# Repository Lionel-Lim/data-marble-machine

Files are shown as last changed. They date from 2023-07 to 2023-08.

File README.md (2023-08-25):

# **Data Marble Machine: A Visual and Interactive Approach to Energy Awareness**

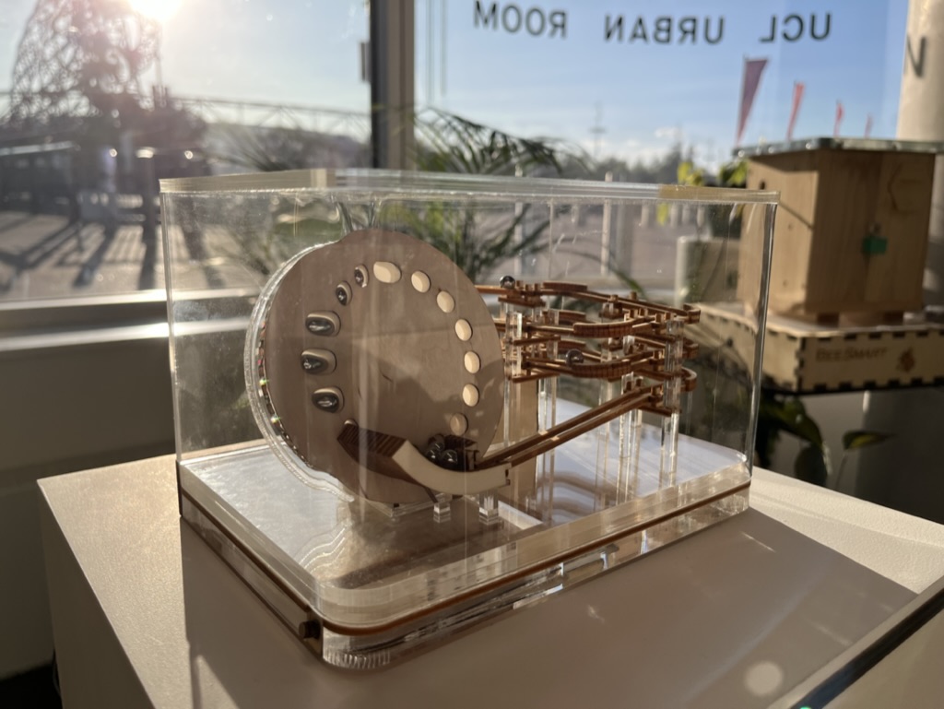
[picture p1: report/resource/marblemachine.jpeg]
Marble Machine on a plinth
<p align="center"> 

## **Project Overview**

This project showcases the innovative "Marble Machine," a device bridging the gap between art and technology. By converting real-time energy consumption data into tangible movement of marbles, this device provides a captivating visual and auditory experience. Accompanied by a user-friendly web application, this project seeks to revolutionise the way users interact with their energy consumption data.

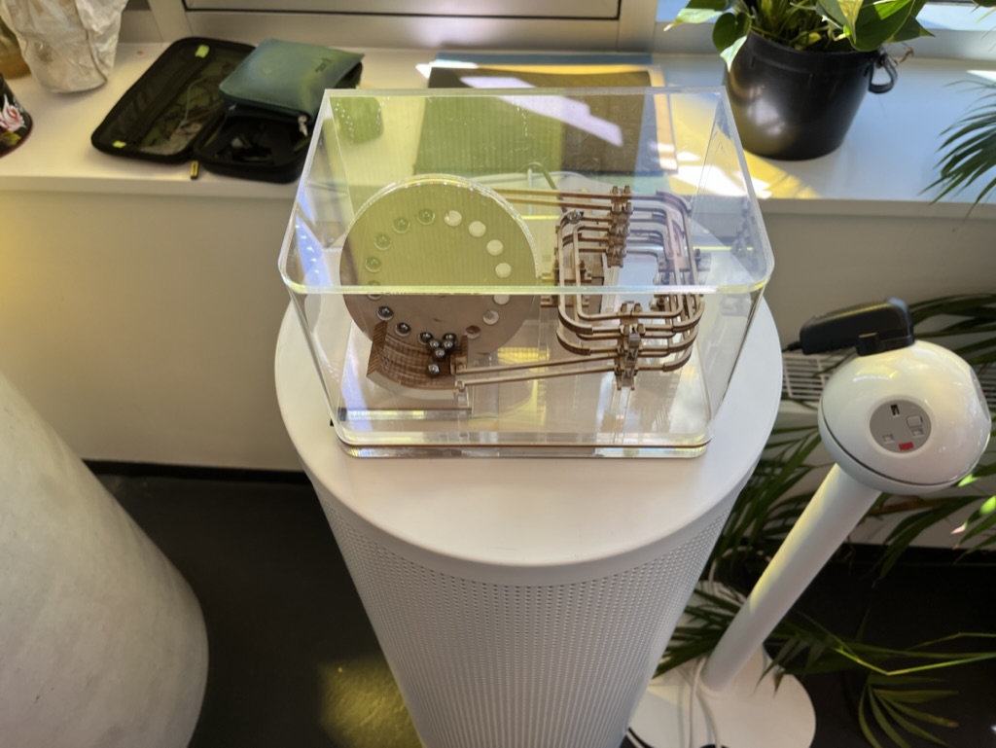
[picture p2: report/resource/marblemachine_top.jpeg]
Marble machine on a pillar
<p align="center"> 

### **Key Features**

- Transforms real-time energy consumption into marble movement.
- Provides both visual and auditory feedback.
- Created using modern techniques like laser cutting and 3D printing.
- Accompanying web application for detailed energy data insights.

## **Getting Started**

### **Prerequisites**

- Ensure you have [Flutter](https://flutter.dev/docs/get-started/install) installed for web application setup.
- Necessary hardware components for the Marble Machine.
- Basic understanding of IoT device operation.

### **Application Installation**

1. **Clone the Repository**

```
git clone https://github.com/Lionel-Lim/data-marble-machine
```

1. Navigate to the cloned directory.
2. Follow the instructions in the 'How to Make' section - Web Application Setup.

## **How to Make**

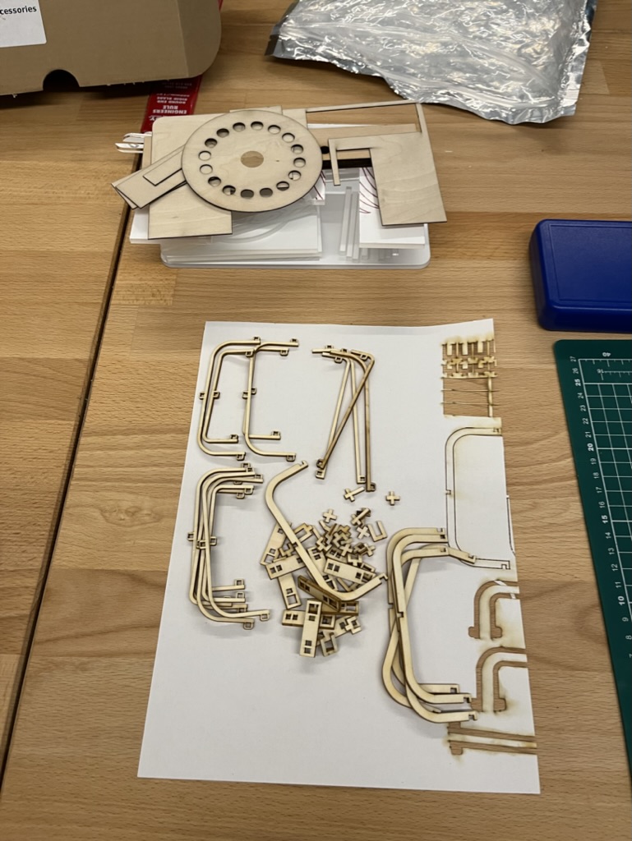
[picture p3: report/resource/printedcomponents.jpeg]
Printed materials
<p align="center"> 

1. **Required Components, Materials and Machines**
- **Components**
    - [Adafruit ESP32 Feather V2 - 8MB Flash + 2 MB PSRAM - STEMMA QT](https://www.adafruit.com/product/5400 "https://www.adafruit.com/product/5400")
    - [Ultra Skinny NeoPixel 1515 LED Strip 4mm wide (0.5 meter long - 75 LEDs)](https://thepihut.com/products/ultra-skinny-neopixel-1515-led-strip-4mm-wide "https://thepihut.com/products/ultra-skinny-neopixel-1515-led-strip-4mm-wide")
    - [DC Motor + Stepper FeatherWing Add-on For All Feather Boards](https://www.adafruit.com/product/2927 "https://www.adafruit.com/product/2927")
    - [Micro Mini N20 DC Motor with gear box](https://www.amazon.co.uk/HALJIA-300RPM-Reducing-Reduction-Terminals/dp/B07YB76TGS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 "https://www.amazon.co.uk/HALJIA-300RPM-Reducing-Reduction-Terminals/dp/B07YB76TGS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")
    - [Female DC Power adapter - 2.1mm jack to screw terminal block](https://thepihut.com/products/female-dc-power-adapter-2-1mm-jack-to-screw-terminal-block "https://thepihut.com/products/female-dc-power-adapter-2-1mm-jack-to-screw-terminal-block")
    - Wires
    - Ball bearing (6mm x 16mm x 6mm)
    - Wooden Dowel Pins (6mm x 30mm)
- **Materials**
    - 1.8, 5, 10mm Transparent Acrylic Sheet
    - 1, 2.5, 5mm Wood Sheet
- **Machines**
    - Trotec Speedy 400 or equivalent
    - Prusa i3 MK3S or equivalent

3. **Hardware Setup**
- Navigate to `models/final`
- Cut required components as per the name of the files.
- Assemble the primary structure using the laser-cut pieces.
- Integrate the sensors and ensure they are correctly calibrated.
- Connect the device to a power source.
2. **Web Application Setup**
- **Start from beginning**
    - Navigate to the `code/app/elow` directory.
    - Install necessary dependencies using `flutter pub get`.
    - Run the application using `flutter run`. (Tested in Edge, Android and iOS)
- or use pre-built files
    - Navigate to `firebase/public` 
    - Upload all files to hosting platform

## Circuit Diagram
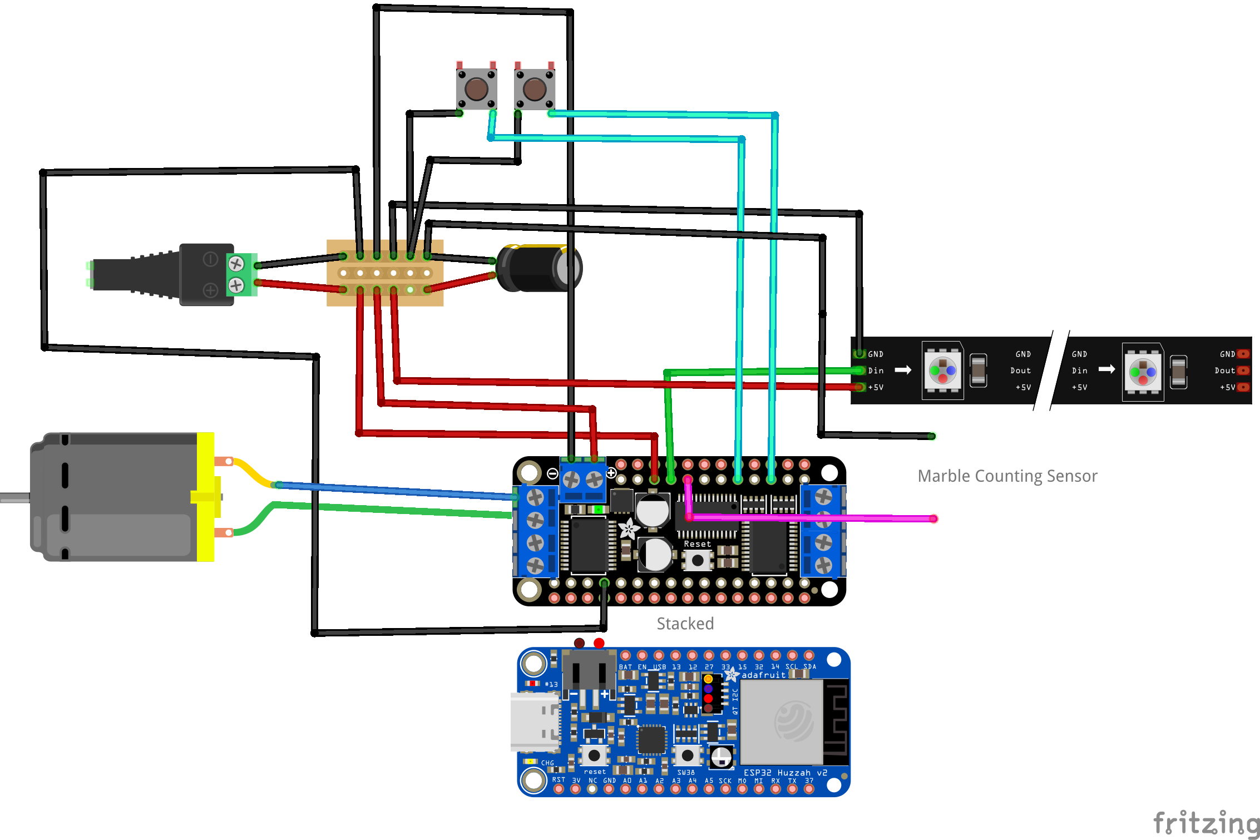
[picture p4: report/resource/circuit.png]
Circuit Diagram
<p align="center"> 

## Exhibition
The project is currently on public display at UCL East Urban Room.

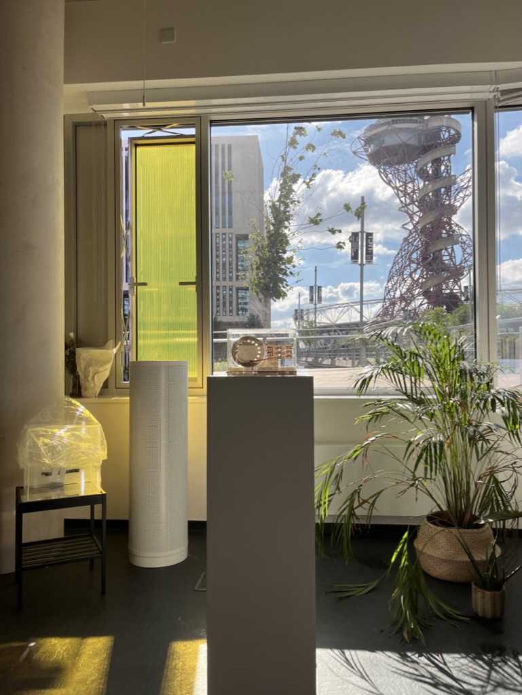
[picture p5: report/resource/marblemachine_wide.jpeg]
Exhibited Project
<p align="center"> 

##

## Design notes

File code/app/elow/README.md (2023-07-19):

# elow

A new Flutter project.

## Getting Started

This project is a starting point for a Flutter application.

A few resources to get you started if this is your first Flutter project:

- [Lab: Write your first Flutter app](https://docs.flutter.dev/get-started/codelab)
- [Cookbook: Useful Flutter samples](https://docs.flutter.dev/cookbook)

For help getting started with Flutter development, view the
[online documentation](https://docs.flutter.dev/), which offers tutorials,
samples, guidance on mobile development, and a full API reference.

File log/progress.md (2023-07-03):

# Making progress
## 24 June 2023
1. Selecting suitable LED Strip
   1. They are usually 12mm thickness.
   2. Adafruit provides 4mm thickness LED strip. but not durable.
## 25 June 2023
1. The marble machine design is not suitable for moving parts.
2. Acrylic glue is reacting with fingerprint
## 26 June 2023
1. Tried different materials for the wheel.
   1. Transparent Acrylic
      1. Glue is visiable
   2. Printed Acrylic
      1. UV printed wheel
      2. Need more design research to be fit in the mood.
   3. Wood
      1. Possible solution
2. Tested the basic DC Motor
   1. The test shows the torque of the basic DC motor is not enough.
      1. Need to find a better DC motor
   2. Also, the minimum speed is too fast.
      1. Need to add gears.
      2. **This affect design changes.**
3. Easy assembly required for wheel systems
   1. It is hard to assemble and disassemble the parts.

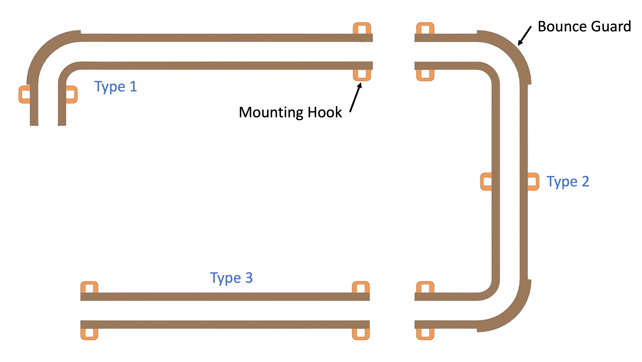
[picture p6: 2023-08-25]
report/resource/tracks.png

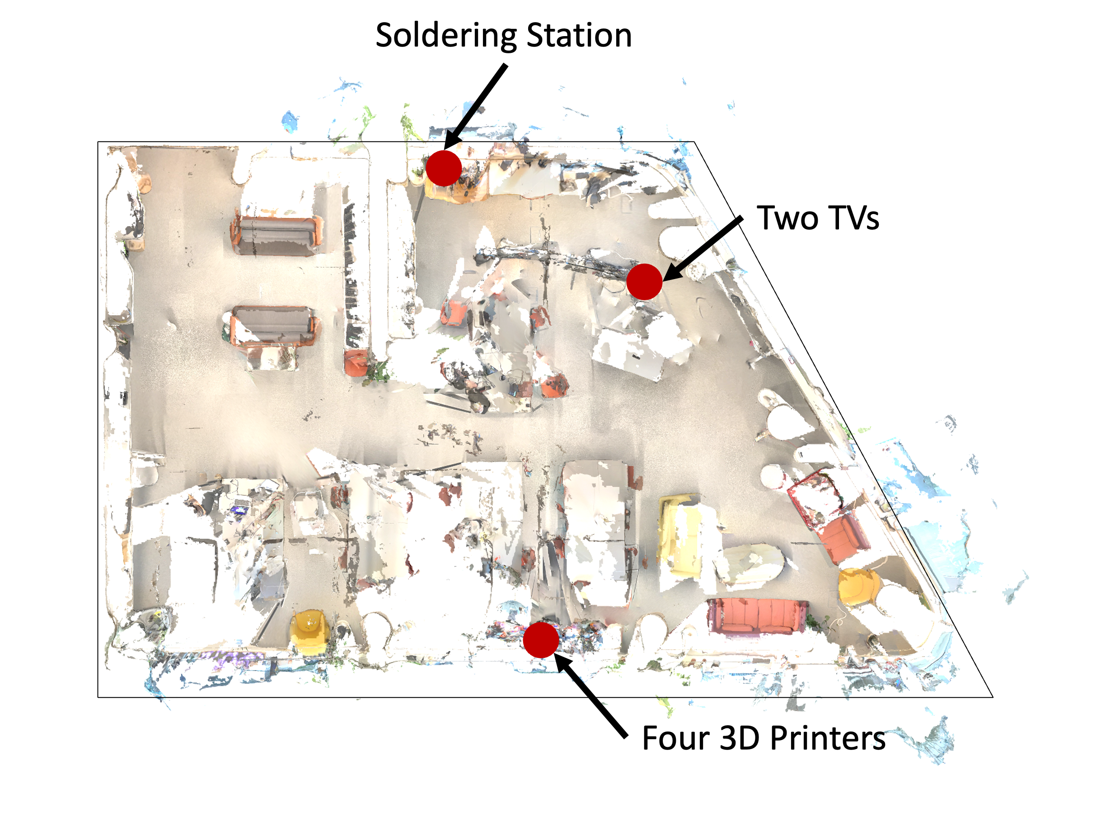
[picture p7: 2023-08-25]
report/resource/CE.png

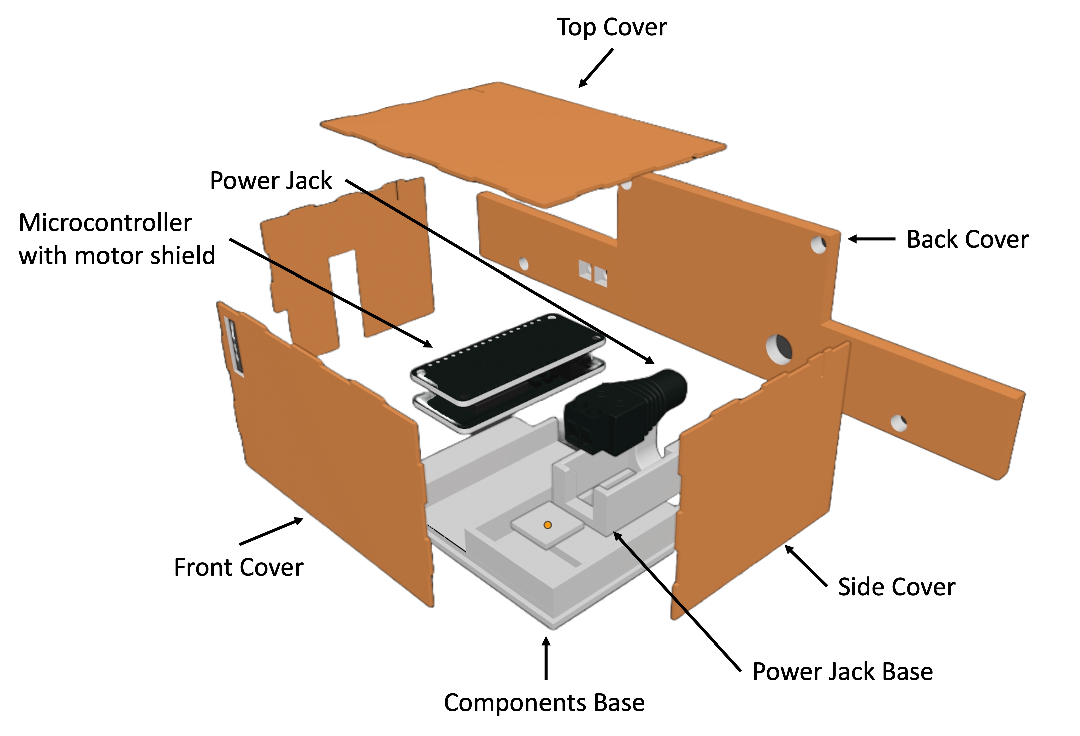
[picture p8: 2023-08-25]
report/resource/controller.png

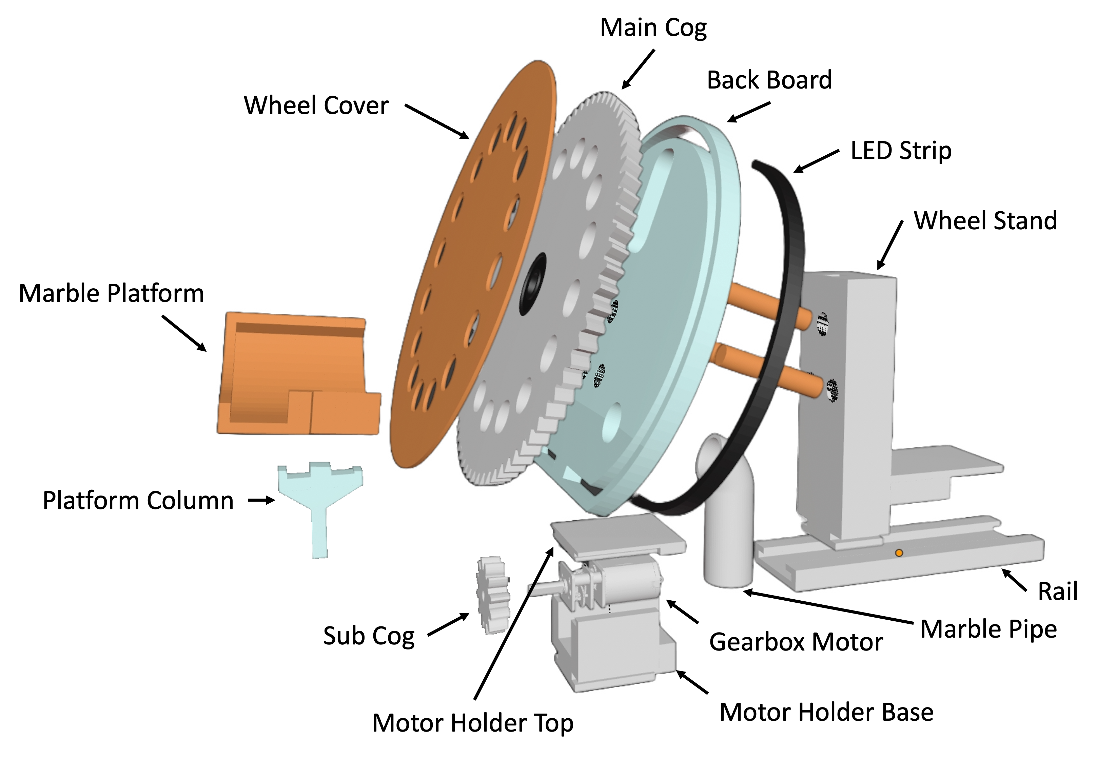
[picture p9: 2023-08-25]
report/resource/wheel system.png

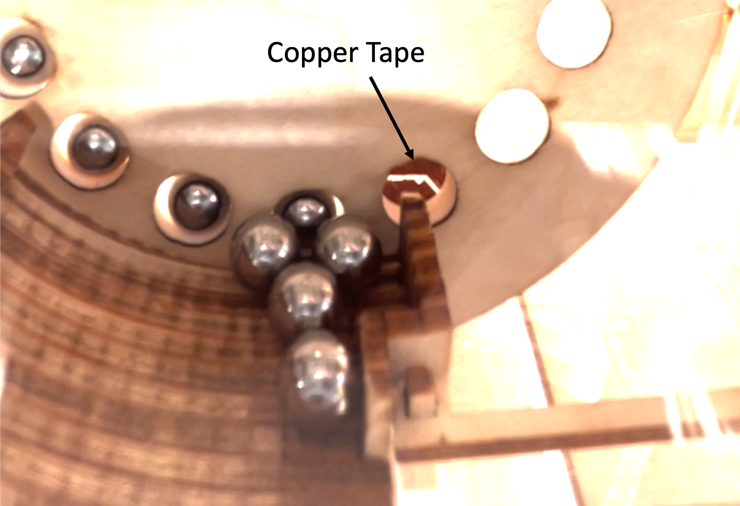
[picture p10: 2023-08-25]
report/resource/copper tape.png

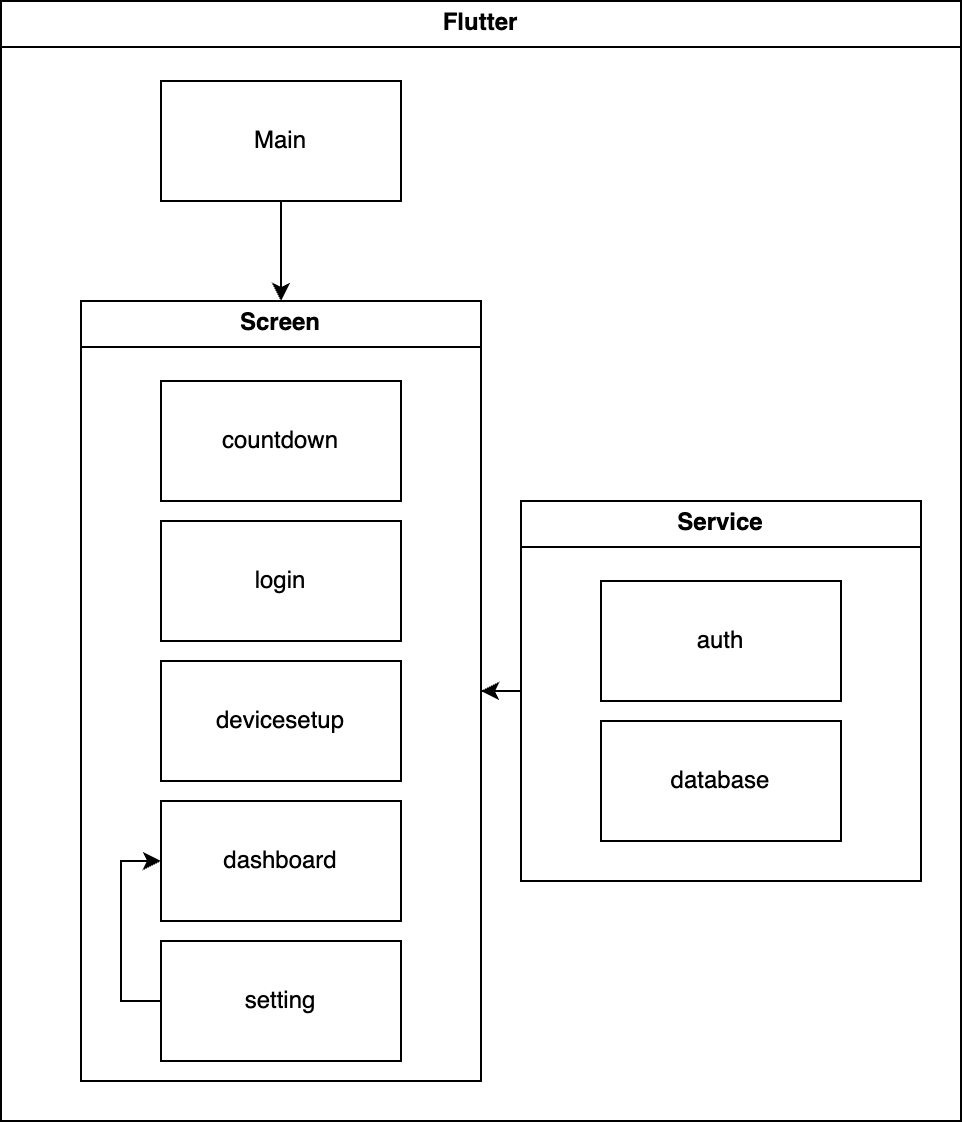
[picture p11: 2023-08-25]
report/resource/flutter.png

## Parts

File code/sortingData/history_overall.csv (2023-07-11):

id | time | today | yesterday | total
-NZRIsscOZ8BlWvMjwk2 | 2023-07-03T16:12:01 | 0.415 | 0.625 | 417.82602
-NZRbnxrCrvrV9LD0hz4 | 2023-07-03T17:39:01 | 0.47 | 0.625 | 417.87997
-NZRvRwlz3w-YxZqH1De | 2023-07-03T19:04:52 | 0.512 | 0.625 | 417.922
-NZS1JP7hxxVwseaKqFB | 2023-07-03T19:34:52 | 0.524 | 0.625 | 417.93402
-NZS8ArQTFZ809l5P3Cc | 2023-07-03T20:04:52 | 0.535 | 0.625 | 417.94601
-NZSF2JliKqmZRA8X8zq | 2023-07-03T20:34:52 | 0.547 | 0.625 | 417.95801
-NZSLumkIqRtARtkcKyV | 2023-07-03T21:04:52 | 0.559 | 0.625 | 417.97098
-NZSSmEeMSP5T4RriYVt | 2023-07-03T21:34:52 | 0.572 | 0.625 | 417.983
-NZSZdg_HnxORsCF0tpN | 2023-07-03T22:04:52 | 0.585 | 0.625 | 417.99597
-NZSfW8zhdLKZ3aiapcx | 2023-07-03T22:34:52 | 0.596 | 0.625 | 418.00696
-NZSmNbMtPXu513eJRiO | 2023-07-03T23:04:52 | 0.607 | 0.625 | 418.01898
-NZStF3g3Tb_5VGIO9FH | 2023-07-03T23:34:52 | 0.62 | 0.625 | 418.03098
-NZT-6Yc3RIqhELRj_CI | 2023-07-04T00:04:52 | 0.002 | 0.629 | 418.04199
-NZT5yz0UnLYHAqotVXa | 2023-07-04T00:34:52 | 0.013 | 0.629 | 418.05298
-NZTCqRVxH8izHTPXCXN | 2023-07-04T01:04:52 | 0.025 | 0.629 | 418.064
-NZTJhtXt2rQD7xAADGL | 2023-07-04T01:34:52 | 0.036 | 0.629 | 418.07599
-NZTQ_M70p0UNS-J6Qpl | 2023-07-04T02:04:52 | 0.047 | 0.629 | 418.08698
-NZTXRoBZW2lJ6molRjY | 2023-07-04T02:34:52 | 0.058 | 0.629 | 418.099
-NZTdJGb0Y1wPdb23wPc | 2023-07-04T03:04:52 | 0.071 | 0.629 | 418.11099
-NZTkAibS05ahoGTkV59 | 2023-07-04T03:34:52 | 0.083 | 0.629 | 418.12302
-NZTr2AyBFbIGBYkgi1e | 2023-07-04T04:04:52 | 0.094 | 0.629 | 418.134
-NZTxudAdf8F0vrcKbdG | 2023-07-04T04:34:52 | 0.106 | 0.629 | 418.14597
-NZU3m5UD1iuTVRs56pe | 2023-07-04T05:04:52 | 0.117 | 0.629 | 418.15698
-NZUAdZLoMnkoAhK8iS_ | 2023-07-04T05:34:52 | 0.129 | 0.629 | 418.16898
-NZUHW01LpOlcrG2XYTf | 2023-07-04T06:04:52 | 0.141 | 0.629 | 418.17999
-NZUONTVVsOEsC8XpFBN | 2023-07-04T06:34:52 | 0.153 | 0.629 | 418.19199
-NZUVEvXE3ZSI4jXge1G | 2023-07-04T07:04:52 | 0.164 | 0.629 | 418.203
-NZUb6OMqLoZTQ4nwf8- | 2023-07-04T07:34:52 | 0.175 | 0.629 | 418.21399
-NZUhyqMOaAzW_AxK54V | 2023-07-04T08:04:52 | 0.187 | 0.629 | 418.22498
-NZUoqJ4aIE2AZiSsIjd | 2023-07-04T08:34:52 | 0.2 | 0.629 | 418.23898
-NZUvhlAh6O4QZdCflVE | 2023-07-04T09:04:52 | 0.211 | 0.629 | 418.25098
-NZV1_FQ1UYfBWhxtNMZ | 2023-07-04T09:34:52 | 0.223 | 0.629 | 418.26199
-NZV8RfZwunwgG6mrAcd | 2023-07-04T10:04:52 | 0.236 | 0.629 | 418.27399
-NZVFJ7mQzROLqug1ncZ | 2023-07-04T10:34:52 | 0.287 | 0.629 | 418.32703
-NZVMAagM1g01QqAxkSv | 2023-07-04T11:04:52 | 0.344 | 0.629 | 418.384
-NZVT22oxxBngN0eI2aS | 2023-07-04T11:34:52 | 0.399 | 0.629 | 418.44
-NZVZuW3jtLXUvRewfIX | 2023-07-04T12:04:52 | 0.454 | 0.629 | 418.495
-NZVflz_n9t7elbhGsOP | 2023-07-04T12:34:52 | 0.508 | 0.629 | 418.548
-NZVnKoY5rRvbtHBqoWb | 2023-07-04T13:07:55 | 0.565 | 0.629 | 418.60501
-NZVuCGlD9WMh9bg6SUk | 2023-07-04T13:37:55 | 0.617 | 0.629 | 418.65698
-NZW03ixegD8hLxJqiv4 | 2023-07-04T14:07:55 | 0.667 | 0.629 | 418.70798
-NZW6wF7A69tJ0z4xR25 | 2023-07-04T14:37:55 | 0.718 | 0.629 | 418.758
-NZWDndfc2KWd0dBMuno | 2023-07-04T15:07:55 | 0.768 | 0.629 | 418.80701
-NZWKf5q36tfwtnQHKAf | 2023-07-04T15:37:55 | 0.788 | 0.629 | 418.828
-NZWRXYvdeC1B7Hd-8WQ | 2023-07-04T16:07:55 | 0.811 | 0.629 | 418.85098
-NZWYP0RLn5qxZ-cUF9_ | 2023-07-04T16:37:55 | 0.826 | 0.629 | 418.867
-NZWeGTiTPwK1BbOZ3xP | 2023-07-04T17:07:55 | 0.842 | 0.629 | 418.88199
-NZWl7x_T9pxJDoXAZCq | 2023-07-04T17:37:55 | 0.856 | 0.629 | 418.89499
-NZWs-OLWvmGEvcayv3h | 2023-07-04T18:07:55 | 0.867 | 0.629 | 418.90695
-NZWyrqTp2Q0_ry1DlZc | 2023-07-04T18:37:55 | 0.879 | 0.629 | 418.91898
-NZX4jIooaXTy5k-6vXw | 2023-07-04T19:07:55 | 0.892 | 0.629 | 418.93204
-NZXBalFWzIwCsPStxiO | 2023-07-04T19:37:55 | 0.904 | 0.629 | 418.94302
-NZXITDQC2_9kcznhuIY | 2023-07-04T20:07:55 | 0.916 | 0.629 | 418.95502
-NZXPKfoPOIllsCwBLYN | 2023-07-04T20:37:55 | 0.927 | 0.629 | 418.96603
-NZXWC90hKIZbGCj3i-K | 2023-07-04T21:07:55 | 0.938 | 0.629 | 418.978
-NZXc3aGrjJiSsTcricL | 2023-07-04T21:37:55 | 0.95 | 0.629 | 418.98999
-NZXiw2c46k66Wz9k6yw | 2023-07-04T22:07:55 | 0.961 | 0.629 | 419.00195
-NZXpnVlD3GGOwagnGgI | 2023-07-04T22:37:55 | 0.973 | 0.629 | 419.01297
-NZXwey3c7BF5NFW7wGG | 2023-07-04T23:07:55 | 0.984 | 0.629 | 419.02402
-NZY2XQZPElz6eom8JzB | 2023-07-04T23:37:55 | 0.996 | 0.629 | 419.035
-NZY9OsyS_LsVVh8cmMD | 2023-07-05T00:07:55 | 0.004 | 1.004 | 419.04703
-NZYGGL8uu8Z8DCWwRnP | 2023-07-05T00:37:55 | 0.015 | 1.004 | 419.06003
-NZYN7nwxNTG1W313v4h | 2023-07-05T01:07:55 | 0.026 | 1.004 | 419.07101
-NZYU-FpWYO_jgVHa5eI | 2023-07-05T01:37:56 | 0.038 | 1.004 | 419.082
-NZY_rjM6vJdov1lWVPy | 2023-07-05T02:07:56 | 0.049 | 1.004 | 419.09402
-NZYgj9o1Bh0NgVR__vs | 2023-07-05T02:37:56 | 0.061 | 1.004 | 419.10501
-NZYnac48HWQXfqnhGRI | 2023-07-05T03:07:56 | 0.072 | 1.004 | 419.116
-NZYuT4UtPE8nK36237v | 2023-07-05T03:37:56 | 0.084 | 1.004 | 419.12799
-NZZ0KXfwbbcOgdxnqTd | 2023-07-05T04:07:56 | 0.096 | 1.004 | 419.13998
-NZZ7Bzn2IxgjSRdUHJr | 2023-07-05T04:37:56 | 0.107 | 1.004 | 419.15097
-NZZE3ShlMKwAYKrSSzi | 2023-07-05T05:07:56 | 0.118 | 1.004 | 419.16299
-NZZKvueg2DHGGXsADr- | 2023-07-05T05:37:56 | 0.132 | 1.004 | 419.17599
-NZZRnMgI39p1Rl5fm0x | 2023-07-05T06:07:56 | 0.144 | 1.004 | 419.18802
-NZZYep7nARvGAL_yQKY | 2023-07-05T06:37:56 | 0.155 | 1.004 | 419.20001
-NZZeXHq0TMFqEIMKqVF | 2023-07-05T07:07:56 | 0.166 | 1.004 | 419.211
-NZZlOjwB8Bk5ZwHyCkE | 2023-07-05T07:37:56 | 0.178 | 1.004 | 419.22198
-NZZsGCFHLwtDOlVW0BH | 2023-07-05T08:07:56 | 0.189 | 1.004 | 419.23398
-NZZz7f3PC4p7eSskag4 | 2023-07-05T08:37:56 | 0.202 | 1.004 | 419.246
-NZ_5-71lZg9Vc2Zi8ro | 2023-07-05T09:07:56 | 0.213 | 1.004 | 419.25699
-NZ_Br_94-P72FWvVH_5 | 2023-07-05T09:37:56 | 0.225 | 1.004 | 419.26999
-NZ_Ij3BY_JFdcsum-vH | 2023-07-05T10:07:56 | 0.236 | 1.004 | 419.28101
-NZ_PaV-7XMmfBG3cZEw | 2023-07-05T10:37:56 | 0.247 | 1.004 | 419.29199
-NZ_WSws9eEWUSI5H7Ia | 2023-07-05T11:07:56 | 0.262 | 1.004 | 419.30597
-NZ_cKPRFE5HRZf8KdDr | 2023-07-05T11:37:56 | 0.274 | 1.004 | 419.31799
-NZ_jBrsTZyRexzLWPf6 | 2023-07-05T12:07:56 | 0.286 | 1.004 | 419.32999
-NZ_q3JpysBvQZa0fmTm | 2023-07-05T12:37:56 | 0.298 | 1.004 | 419.34198
-NZ_wvw6JzI44dhS4Jrh | 2023-07-05T13:07:56 | 0.309 | 1.004 | 419.35297
-NZa2nFma9bBKScCPMZK | 2023-07-05T13:37:56 | 0.32 | 1.004 | 419.36398
-NZa9eia0DT8XeeECV0V | 2023-07-05T14:07:56 | 0.333 | 1.004 | 419.37701
-NZaGXAOyc1Ctj6ZW2bi | 2023-07-05T14:37:56 | 0.363 | 1.004 | 419.40796
-NZaNOctCQF8mM6V0oBe | 2023-07-05T15:07:56 | 0.408 | 1.004 | 419.45096
-NZaUG5PtcOWYdDYTucN | 2023-07-05T15:37:56 | 0.422 | 1.004 | 419.46802
-NZaa7YKRMM5q2vZtpeJ | 2023-07-05T16:07:56 | 0.437 | 1.004 | 419.483
-NZah--_LwFw37xll5Ce | 2023-07-05T16:37:56 | 0.454 | 1.004 | 419.49902
-NZanrTB2DWFvBasDkvU | 2023-07-05T17:07:56 | 0.47 | 1.004 | 419.51398
-NZauiwNtRPPpcJNM_ck | 2023-07-05T17:37:56 | 0.494 | 1.004 | 419.53702
-NZb0aNrMLfF-MSFbdqv | 2023-07-05T18:07:56 | 0.508 | 1.004 | 419.55298
-NZb7SqLEg9aiSiMuWd7 | 2023-07-05T18:37:56 | 0.52 | 1.004 | 419.56396
-NZbEKI5qCuAPanESmm2 | 2023-07-05T19:07:56 | 0.531 | 1.004 | 419.57599
-NZbLBkjR94mkpMDVP3k | 2023-07-05T19:37:56 | 0.544 | 1.004 | 419.58798
-NZbS3CuRMEVLASQjJjy | 2023-07-05T20:07:56 | 0.555 | 1.004 | 419.599
-NZbYvfKvlk9HfMIo-ji | 2023-07-05T20:37:56 | 0.566 | 1.004 | 419.61002
-NZben7bqkBA9MHE-L6G | 2023-07-05T21:07:56 | 0.578 | 1.004 | 419.62198
-NZble_zg77rB3EkmnGf | 2023-07-05T21:37:56 | 0.589 | 1.004 | 419.634
-NZbsX1kOjk_-OmAg2py | 2023-07-05T22:07:56 | 0.602 | 1.004 | 419.646
-NZbzOV70dQH4GDdbXBH | 2023-07-05T22:37:56 | 0.615 | 1.004 | 419.65897
-NZc5FzIb_6yV89wsmKw | 2023-07-05T23:07:56 | 0.627 | 1.004 | 419.66998
-NZcC7QR0BiPM28-Ynw2 | 2023-07-05T23:37:56 | 0.639 | 1.004 | 419.681
-NZcIzsB7-zIGxChyw7t | 2023-07-06T00:07:56 | 0.003 | 0.647 | 419.694
-NZcPrKChsPXUW3JHj0O | 2023-07-06T00:37:56 | 0.014 | 0.647 | 419.70599
-NZcWim_3USZzzZU3dJW | 2023-07-06T01:07:55 | 0.026 | 0.647 | 419.71701
-NZccaEv1q-2oZVjKvsB | 2023-07-06T01:37:56 | 0.037 | 0.647 | 419.729
-NZcjShoX-KKGaYw9D9O | 2023-07-06T02:07:56 | 0.049 | 0.647 | 419.73999
-NZcqK9bFn0JiRRIqcFQ | 2023-07-06T02:37:56 | 0.061 | 0.647 | 419.75101
-NZcxBbywXWEXzd2ST7P | 2023-07-06T03:07:56 | 0.073 | 0.647 | 419.763
-NZd333cJ-HzdQ10ZKIv | 2023-07-06T03:37:56 | 0.085 | 0.647 | 419.77502
-NZd9vWt9PHTTea4ku6V | 2023-07-06T04:07:56 | 0.096 | 0.647 | 419.78699
-NZdGn-Bl9XV-eiYQdWa | 2023-07-06T04:37:56 | 0.107 | 0.647 | 419.798
-NZdNeUU0_dnbHaSczvX | 2023-07-06T05:07:56 | 0.12 | 0.647 | 419.81
-NZdUWvQzzkHkWRSEaZl | 2023-07-06T05:37:56 | 0.131 | 0.647 | 419.82199
-NZdaOMKqHS174HEVgcD | 2023-07-06T06:07:56 | 0.142 | 0.647 | 419.83398
-NZdhFobXJwfbi2NnXFX | 2023-07-06T06:37:56 | 0.154 | 0.647 | 419.845
-NZdo7H34NhtZtRijXpg | 2023-07-06T07:07:56 | 0.166 | 0.647 | 419.85599
-NZduzjrT30xCVeZQaxy | 2023-07-06T07:37:56 | 0.177 | 0.647 | 419.86798
-NZe0rBibeGFBGoLtUFv | 2023-07-06T08:07:56 | 0.189 | 0.647 | 419.879
-NZe7idz-XXSYaFZn_Op | 2023-07-06T08:37:56 | 0.201 | 0.647 | 419.89001
-NZeEa5t77kdKmD_jDNi | 2023-07-06T09:07:56 | 0.214 | 0.647 | 419.90399
-NZeLSZCW3Hwmkjtiumq | 2023-07-06T09:37:56 | 0.226 | 0.647 | 419.91699
-NZeSK3k8-KhPyE26_OZ | 2023-07-06T10:07:56 | 0.238 | 0.647 | 419.92798
-NZeZBUFJv_meFyzJE70 | 2023-07-06T10:37:56 | 0.249 | 0.647 | 419.939
-NZef2w205epjRiRS3vd | 2023-07-06T11:07:56 | 0.261 | 0.647 | 419.95099
-NZelvOGOwlIee7FreqP | 2023-07-06T11:37:56 | 0.272 | 0.647 | 419.96201
-NZesmr4yKKDN7_iG6S3 | 2023-07-06T12:07:56 | 0.284 | 0.647 | 419.97403
-NZezeJhIbbchlAYumHk | 2023-07-06T12:37:56 | 0.295 | 0.647 | 419.98602
-NZf5WlNRyEJph1latOa | 2023-07-06T13:07:56 | 0.306 | 0.647 | 419.99701
-NZfCODXyFRg6yCz6flf | 2023-07-06T13:37:56 | 0.317 | 0.647 | 420.008
-NZfJFftNyWC-nd-85_m | 2023-07-06T14:07:56 | 0.33 | 0.647 | 420.01898
-NZfQ7819-2MFf_-n8vZ | 2023-07-06T14:37:56 | 0.345 | 0.647 | 420.03497
-NZfWzaSR0WJc25cU7a- | 2023-07-06T15:07:56 | 0.359 | 0.647 | 420.05099
-NZfcr2roshFim_HMOuj | 2023-07-06T15:37:56 | 0.375 | 0.647 | 420.06598
-NZfjiW_vpjI_H0p6gUN | 2023-07-06T16:07:56 | 0.39 | 0.647 | 420.082
-NZfq_yVotRpBoudGN5A | 2023-07-06T16:37:56 | 0.406 | 0.647 | 420.09601
-NZfxSQrRt9Jn3vNG0Pi | 2023-07-06T17:07:56 | 0.434 | 0.647 | 420.12399
-NZg3Jslwbl3OmKTZkar | 2023-07-06T17:37:56 | 0.446 | 0.647 | 420.13699
-NZgABLJPxPVflIgqKWT | 2023-07-06T18:07:56 | 0.458 | 0.647 | 420.14899
-NZgH2nd08RSVbusrIRS | 2023-07-06T18:37:56 | 0.469 | 0.647 | 420.16098
-NZgNvFbAVqbsb-bo2t0 | 2023-07-06T19:07:56 | 0.481 | 0.647 | 420.17203
-NZgUmiZDJUz9ovhJg-- | 2023-07-06T19:37:56 | 0.494 | 0.647 | 420.18304
-NZgaeAGVtiJkNziORRq | 2023-07-06T20:07:56 | 0.505 | 0.647 | 420.19504
-NZghWc_-A8c6APx8QiZ | 2023-07-06T20:37:57 | 0.516 | 0.647 | 420.20703
-NZgoO99QPF0XzH-yiC- | 2023-07-06T21:07:57 | 0.528 | 0.647 | 420.21802
-NZgvFYZzVStAWOjalr7 | 2023-07-06T21:37:57 | 0.539 | 0.647 | 420.22903
-NZh17-eV9-3AHYpMOIN | 2023-07-06T22:07:57 | 0.55 | 0.647 | 420.241
-NZh7zTUDYm5XYz4tJ-L | 2023-07-06T22:37:57 | 0.562 | 0.647 | 420.25198
-NZhEqut_9BNEl109YRq | 2023-07-06T23:07:57 | 0.574 | 0.647 | 420.26395
-NZhLiNAi8uFIwQxSDId | 2023-07-06T23:37:57 | 0.585 | 0.647 | 420.27704
-NZhS_pdQytYZ1brKRu- | 2023-07-07T00:07:57 | 0.003 | 0.594 | 420.28903
-NZhZSIcym_RhJHXwENe | 2023-07-07T00:37:57 | 0.015 | 0.594 | 420.30002
-NZhfJkcyb34gzPB_437 | 2023-07-07T01:07:57 | 0.026 | 0.594 | 420.31201
-NZhmBD2QPDY0TfpcJsV | 2023-07-07T01:37:57 | 0.037 | 0.594 | 420.32303
-NZht2eTPhROamduKH7n | 2023-07-07T02:07:57 | 0.049 | 0.594 | 420.33401
-NZhzv6gmKqBNcyCOD8M | 2023-07-07T02:37:57 | 0.062 | 0.594 | 420.34698
-NZi5m_BTrOR-RXSpAl7 | 2023-07-07T03:07:57 | 0.073 | 0.594 | 420.35797
-NZiCe1xiAIXifrcfsCA | 2023-07-07T03:37:57 | 0.084 | 0.594 | 420.36899
-NZiJWUWIgvILDOvb9xk | 2023-07-07T04:07:57 | 0.096 | 0.594 | 420.38101
-NZiQNx3JaqinXrUMVfq | 2023-07-07T04:37:57 | 0.107 | 0.594 | 420.39301
-NZiXFP68PJpX6iom2p3 | 2023-07-07T05:07:57 | 0.119 | 0.594 | 420.40402
-NZid6rm3aJWgazTaT13 | 2023-07-07T05:37:57 | 0.131 | 0.594 | 420.41702
-NZijzJsPJaqbSrHHXRZ | 2023-07-07T06:07:57 | 0.144 | 0.594 | 420.42801
-NZiqqlnYHLVgnvbLawR | 2023-07-07T06:37:57 | 0.155 | 0.594 | 420.44
-NZixiE2vzaDZ0dsRnUg | 2023-07-07T07:07:57 | 0.166 | 0.594 | 420.45102
-NZj3_gS7VHAHXljXjRU | 2023-07-07T07:37:57 | 0.177 | 0.594 | 420.46201
-NZjAS8xxraIeJPl1XDS | 2023-07-07T08:07:57 | 0.189 | 0.594 | 420.47299
-NZjHJbVy0StleuCt8ZE | 2023-07-07T08:37:57 | 0.201 | 0.594 | 420.487
-NZjOBJaypmY_kzs2M5c | 2023-07-07T09:07:57 | 0.212 | 0.594 | 420.49802
-NZjV2Wm6go3EKU1KVFF | 2023-07-07T09:37:57 | 0.223 | 0.594 | 420.509
-NZjauzP_ZcMFDCSBtwX | 2023-07-07T10:07:57 | 0.235 | 0.594 | 420.521
-NZjhmRJ1_vVhX-QWrxM | 2023-07-07T10:37:57 | 0.266 | 0.594 | 420.55099
-NZjoduAmJhizfaltSrx | 2023-07-07T11:07:57 | 0.283 | 0.594 | 420.56699
-NZjvWLnHc9bGWirJcmn | 2023-07-07T11:37:57 | 0.299 | 0.594 | 420.58301
-NZk1NoLpKh6oq9WU7GT | 2023-07-07T12:07:57 | 0.314 | 0.594 | 420.599
-NZk8FGp2fQN5uvLlz7t | 2023-07-07T12:37:57 | 0.336 | 0.594 | 420.62097
-NZkFBoQfYeXau-f-I1m | 2023-07-07T13:07:57 | 0.417 | 0.594 | 420.702
-NZkM-HyEvMHWJNHJznP | 2023-07-07T13:38:03 | 0.436 | 0.594 | 420.72202
-NZkSrhysyR1z2PI6hQ2 | 2023-07-07T14:08:03 | 0.483 | 0.594 | 420.76898
-NZkZjAz-53uaGt7blDg | 2023-07-07T14:38:00 | 0.527 | 0.594 | 420.81302
-NZkfacB8vc1xDxXDXDT | 2023-07-07T15:08:03 | 0.538 | 0.594 | 420.82401
-NZkmT56dfj1jY0yDEdq | 2023-07-07T15:38:03 | 0.554 | 0.594 | 420.83902
-NZktKY1o2R_YCsBvKbD | 2023-07-07T16:08:03 | 0.571 | 0.594 | 420.85602
-NZl-C-KhFCIS5iCNuS3 | 2023-07-07T16:38:03 | 0.583 | 0.594 | 420.86801
-NZl63V3O18UXB2OE78t | 2023-07-07T17:08:03 | 0.598 | 0.594 | 420.88303
-NZlCxIIh7bw3pFeSVjd | 2023-07-07T17:38:00 | 0.612 | 0.594 | 420.896
-NZlJnNAVMo3SsmE2Woa | 2023-07-07T18:08:03 | 0.623 | 0.594 | 420.909
-NZlQepSAoKXoIfgQx5Y | 2023-07-07T18:38:03 | 0.634 | 0.594 | 420.92001
-NZlXYLSIY6mCTxBdOWL | 2023-07-07T19:08:00 | 0.646 | 0.594 | 420.931
-NZldOkoxr_e2aSpjYeg | 2023-07-07T19:38:03 | 0.659 | 0.594 | 420.94299
-NZlkGCJKc7jUzcg_-n3 | 2023-07-07T20:08:03 | 0.67 | 0.594 | 420.95502
-NZlr7f5TS8kYSTsiLAk | 2023-07-07T20:38:03 | 0.681 | 0.594 | 420.96704
-NZly-76pe5ccBzkaG3n | 2023-07-07T21:08:03 | 0.692 | 0.594 | 420.97803
-NZm3r_Em71eltXDahTR | 2023-07-07T21:38:03 | 0.705 | 0.594 | 420.991
-NZmAj1N1svIwe-AAWu6 | 2023-07-07T22:08:03 | 0.718 | 0.594 | 421.00403
-NZmHaUq9Dz3SLroX4Nn | 2023-07-07T22:38:03 | 0.73 | 0.594 | 421.01501
-NZmOSx3Z3zzRW3j9R_t | 2023-07-07T23:08:03 | 0.742 | 0.594 | 421.02701
-NZmVKPJuJf8MY3ImqAH | 2023-07-07T23:38:03 | 0.753 | 0.594 | 421.039
-NZmbBreWPMJBKKawjBY | 2023-07-08T00:08:03 | 0.003 | 0.761 | 421.05005
-NZmi3K1tGz-ZRv2eNYt | 2023-07-08T00:38:03 | 0.014 | 0.761 | 421.06104
-NZmovmBPcxs0lBy1StE | 2023-07-08T01:08:03 | 0.026 | 0.761 | 421.073
-NZmvnEncyWICNdR0FAW | 2023-07-08T01:38:03 | 0.037 | 0.761 | 421.08401
-NZn1egYn3r7wD9un1I- | 2023-07-08T02:08:03 | 0.049 | 0.761 | 421.09598
-NZn8X94dD1mflkLFYT6 | 2023-07-08T02:38:03 | 0.06 | 0.761 | 421.10699
-NZnFObKPgR-YVSLkM0c | 2023-07-08T03:08:03 | 0.073 | 0.761 | 421.11899
-NZnMG3k3TK4fTE2Su4o | 2023-07-08T03:38:03 | 0.084 | 0.761 | 421.13098
-NZnT7WkMkDc87LqpRsN | 2023-07-08T04:08:03 | 0.095 | 0.761 | 421.142
-NZnZzzNKrlAY-uVnsuc | 2023-07-08T04:38:03 | 0.107 | 0.761 | 421.15302
-NZnfrScKN0-aqSOTkJZ | 2023-07-08T05:08:03 | 0.119 | 0.761 | 421.16602
-NZnmitkBxjbGDwQq3ND | 2023-07-08T05:38:03 | 0.13 | 0.761 | 421.17703
-NZntaLwlC1ONjrfCLRM | 2023-07-08T06:08:03 | 0.141 | 0.761 | 421.18802
-NZo-Sq6c7TE5zaZoYru | 2023-07-08T06:38:03 | 0.153 | 0.761 | 421.20001
-NZo6KGd4Q7WozaTEvcu | 2023-07-08T07:08:03 | 0.165 | 0.761 | 421.21201
-NZoDBits6wKFZEZQhzX | 2023-07-08T07:38:03 | 0.176 | 0.761 | 421.22302
-NZoK3BLHhWoHHBZ0VPs | 2023-07-08T08:08:03 | 0.189 | 0.761 | 421.23599
-NZoQvdUpYc_r6X2hbjo | 2023-07-08T08:38:03 | 0.201 | 0.761 | 421.24799
-NZoXn7sHLMnQeLigZ8t | 2023-07-08T09:08:03 | 0.212 | 0.761 | 421.259
-NZodeZKm91n85sdqRGX | 2023-07-08T09:38:03 | 0.223 | 0.761 | 421.27002
-NZokX0vE29OgmqXIpuj | 2023-07-08T10:08:03 | 0.234 | 0.761 | 421.28101
-NZorOTU1UqG04tLVBMI | 2023-07-08T10:38:03 | 0.246 | 0.761 | 421.29401
-NZoyFwkLAAdG6TkheBq | 2023-07-08T11:08:03 | 0.258 | 0.761 | 421.30499
-NZp47OBZAizUgnHNWu3 | 2023-07-08T11:38:03 | 0.269 | 0.761 | 421.31601
-NZpAzqwXubiCSBvnTLg | 2023-07-08T12:08:03 | 0.28 | 0.761 | 421.32703
-NZpHrJE2DBCUs7BHaWx | 2023-07-08T12:38:03 | 0.293 | 0.761 | 421.33902
-NZpOikzdzvS46ue-DkV | 2023-07-08T13:08:03 | 0.304 | 0.761 | 421.35104
-NZpVaDNu3X-tln0lMl4 | 2023-07-08T13:38:03 | 0.317 | 0.761 | 421.36401
-NZpbSfjw-R_0fkRickF | 2023-07-08T14:08:03 | 0.329 | 0.761 | 421.37601
-NZpiM16KpQ1PCncQYbP | 2023-07-08T14:38:03 | 0.34 | 0.761 | 421.38699
-NZppBl2xi7taG9jef3R | 2023-07-08T15:08:03 | 0.351 | 0.761 | 421.39801
-NZpw3FE4xe9sc8ZE6xG | 2023-07-08T15:38:03 | 0.363 | 0.761 | 421.41
-NZq1vg_beV1th7G2jBR | 2023-07-08T16:08:03 | 0.374 | 0.761 | 421.42099
-NZq8n7m7tLV_GL2XeTP | 2023-07-08T16:38:03 | 0.385 | 0.761 | 421.43301
-NZqFeakeqZwZkBk6Ygl | 2023-07-08T17:08:03 | 0.397 | 0.761 | 421.444
-NZqMX2BvomHy2cVaWSJ | 2023-07-08T17:38:03 | 0.409 | 0.761 | 421.45602
-NZqTOVcC5OeT6elqwaa | 2023-07-08T18:08:03 | 0.421 | 0.761 | 421.46802
-NZq_Fxtjuymkun9wLHU | 2023-07-08T18:38:03 | 0.432 | 0.761 | 421.479
-NZqg7Q7ObTrx_e_U0NM | 2023-07-08T19:08:03 | 0.445 | 0.761 | 421.492
-NZqmzsndOgMli1K3v69 | 2023-07-08T19:38:03 | 0.456 | 0.761 | 421.50299
-NZqtrKjiTaL1whY-nmo | 2023-07-08T20:08:03 | 0.468 | 0.761 | 421.51498
-NZr-imqlFh51UxZ1Gge | 2023-07-08T20:38:03 | 0.48 | 0.761 | 421.52597
-NZr6aFDzpdoaaCsEsgJ | 2023-07-08T21:08:03 | 0.492 | 0.761 | 421.539
-NZrDShb5pgDGLl2206N | 2023-07-08T21:38:03 | 0.503 | 0.761 | 421.55002
-NZrKKA4FNz1EoFrxYBi | 2023-07-08T22:08:03 | 0.514 | 0.761 | 421.561
-NZrRBcicbqXD7PoEZG6 | 2023-07-08T22:38:03 | 0.526 | 0.761 | 421.57202
-NZrY34BYfZcjSeBWcJx | 2023-07-08T23:08:03 | 0.537 | 0.761 | 421.58502
-NZrdvXaMQGpfFhIhIXs | 2023-07-08T23:38:03 | 0.549 | 0.761 | 421.59601
-NZrkn1-VIlL9TH_Ejx4 | 2023-07-09T00:08:03 | 0.003 | 0.558 | 421.60699
-NZrreS0O4-n3oQpE1x3 | 2023-07-09T00:38:03 | 0.014 | 0.558 | 421.61902
-NZryWuUJv5s4pARcCO8 | 2023-07-09T01:08:03 | 0.026 | 0.558 | 421.63004
-NZs4OMkkW4Tng7zsKk4 | 2023-07-09T01:38:03 | 0.037 | 0.558 | 421.64102
-NZsBFovD9WkSpQsWNVQ | 2023-07-09T02:08:03 | 0.048 | 0.558 | 421.65399
-NZsI7HFOCNv4aGPEWrU | 2023-07-09T02:38:03 | 0.06 | 0.558 | 421.66501
-NZsOzjmUIf7Kc-sGP4S | 2023-07-09T03:08:03 | 0.072 | 0.558 | 421.67599
-NZsVrBlIclumrDuPUtf | 2023-07-09T03:38:03 | 0.083 | 0.558 | 421.68698
-NZsbie5b5sHtJk9gRWM | 2023-07-09T04:08:03 | 0.094 | 0.558 | 421.69901
-NZsia6NPjr62dBneZxb | 2023-07-09T04:38:04 | 0.105 | 0.558 | 421.71002
-NZspSZib_CTppO5s6Kb | 2023-07-09T05:08:04 | 0.118 | 0.558 | 421.72302
-NZswK0pwD3smlLOPoLf | 2023-07-09T05:38:03 | 0.13 | 0.558 | 421.73502
-NZt2BW-3n8IFevW2_3d | 2023-07-09T06:08:03 | 0.141 | 0.558 | 421.746
-NZt92yGFe7-G5iurkfY | 2023-07-09T06:38:04 | 0.153 | 0.558 | 421.75702
-NZtFvP0LouLxo5V8rW8 | 2023-07-09T07:08:04 | 0.164 | 0.558 | 421.76801
-NZtMmr32P7H0L4JXIC4 | 2023-07-09T07:38:04 | 0.176 | 0.558 | 421.77997
-NZtTeJsiaBP44_3J4zu | 2023-07-09T08:08:04 | 0.188 | 0.558 | 421.79202
-NZt_Wm5JvWpnX4ajrw5 | 2023-07-09T08:38:04 | 0.2 | 0.558 | 421.80301
-NZtgOEM7SBLCZrppNqi | 2023-07-09T09:08:04 | 0.211 | 0.558 | 421.815
-NZtnFgTxe_fjVKuqAy1 | 2023-07-09T09:38:04 | 0.222 | 0.558 | 421.82599
-NZtu78knoO0o9CDpuHw | 2023-07-09T10:08:04 | 0.234 | 0.558 | 421.83701
-NZu-zbGC4ZV5O_GHRw8 | 2023-07-09T10:38:04 | 0.245 | 0.558 | 421.849
-NZu6r3Q50Fbl0h106Ii | 2023-07-09T11:08:04 | 0.257 | 0.558 | 421.86099
-NZuDiWY1Tny6m1IkrGW | 2023-07-09T11:38:04 | 0.269 | 0.558 | 421.87201
-NZuK_zFt_CEB2wJ44n6 | 2023-07-09T12:08:04 | 0.28 | 0.558 | 421.88403
-NZuRSR7duZ3JhpcnVuG | 2023-07-09T12:38:04 | 0.292 | 0.558 | 421.89502
-NZuYJtK6jwn-Z_Vbwmg | 2023-07-09T13:08:04 | 0.303 | 0.558 | 421.90601
-NZueBLbcDd3dppg_yyW | 2023-07-09T13:38:04 | 0.314 | 0.558 | 421.91901
-NZul2nt7b5CdOVHWpii | 2023-07-09T14:08:04 | 0.325 | 0.558 | 421.93103
-NZurvGNG-Io-yzWdaoQ | 2023-07-09T14:38:04 | 0.338 | 0.558 | 421.94202
-NZuymin5B6xY-HlVnS4 | 2023-07-09T15:08:04 | 0.349 | 0.558 | 421.953
-NZv4eApbn9Xm7NsSmet | 2023-07-09T15:38:04 | 0.362 | 0.558 | 421.966
-NZvBWdD52r3uBFe46SW | 2023-07-09T16:08:04 | 0.375 | 0.558 | 421.97903
-NZvIO5gy5Ru6frnWgn4 | 2023-07-09T16:38:04 | 0.387 | 0.558 | 421.99002
-NZvPFYq2gIdyfkHJqZK | 2023-07-09T17:08:04 | 0.398 | 0.558 | 422.00201
-NZvW70HGJuttQB7eAEp | 2023-07-09T17:38:04 | 0.41 | 0.558 | 422.01398
-NZvbzTaJdshcxDN7LcH | 2023-07-09T18:08:04 | 0.422 | 0.558 | 422.026
-NZviqv_S2Hbq27ywhcV | 2023-07-09T18:38:04 | 0.433 | 0.558 | 422.03699
-NZvpiQAnfWCLJXp0NrD | 2023-07-09T19:08:04 | 0.445 | 0.558 | 422.04898
-NZvw_ryGR8KvEiORS9d | 2023-07-09T19:38:04 | 0.456 | 0.558 | 422.06
-NZw2SITEv9q_Wfvbu26 | 2023-07-09T20:08:04 | 0.468 | 0.558 | 422.07202
-NZw9JlPOFqgxrH9KWrK | 2023-07-09T20:38:04 | 0.48 | 0.558 | 422.08301
-NZwN2fRl1nhgIQHUJsB | 2023-07-09T21:38:04 | 0.504 | 0.558 | 422.10803
-NZwTvSY9FutGvKmcWet | 2023-07-09T22:08:04 | 0.515 | 0.558 | 422.12
-NZw_m_nXXTXuhOX-Cbi | 2023-07-09T22:38:04 | 0.526 | 0.558 | 422.13098
-NZwge1yg73oXKx1zGlS | 2023-07-09T23:08:04 | 0.538 | 0.558 | 422.142
-NZwnWVR-ePTklPZV-br | 2023-07-09T23:38:04 | 0.55 | 0.558 | 422.15399
-NZwuNxqZT4Z5BzgGZv2 | 2023-07-10T00:08:04 | 0.003 | 0.558 | 422.16599
-NZx0FRggr5AXWtMO3gk | 2023-07-10T00:38:04 | 0.014 | 0.558 | 422.177
-NZx76sF1QYZFSGr469A | 2023-07-10T01:08:04 | 0.026 | 0.558 | 422.18802
-NZxDzKTVf8-gX7Z5lKv | 2023-07-10T01:38:04 | 0.037 | 0.558 | 422.19901
-NZxKqmuvZHOF7X-ej1J | 2023-07-10T02:08:04 | 0.049 | 0.558 | 422.211
-NZxRiEv7wr6PTtVHhls | 2023-07-10T02:38:04 | 0.062 | 0.558 | 422.224
-NZxY_haXTwioYETB9fk | 2023-07-10T03:08:04 | 0.075 | 0.558 | 422.237
-NZxeSABFsukHj__alt2 | 2023-07-10T03:38:04 | 0.088 | 0.558 | 422.25101
-NZxlJbi1Lf72A55oUl- | 2023-07-10T04:08:04 | 0.099 | 0.558 | 422.26199
-NZxsB4202jDH733XNeT | 2023-07-10T04:38:04 | 0.111 | 0.558 | 422.27304
-NZxz2Y2W7NOkNNAZKAM | 2023-07-10T05:08:04 | 0.122 | 0.558 | 422.28403
-NZy4uzm13DN6oia-Zzq | 2023-07-10T05:38:04 | 0.134 | 0.558 | 422.29703
-NZyBmSHrCxbNy170Pnx | 2023-07-10T06:08:04 | 0.145 | 0.558 | 422.30801
-NZyIdvNnEj7UPMEeka_ | 2023-07-10T06:38:04 | 0.157 | 0.558 | 422.31903
-NZyPWMGJnkrp1GyMWLR | 2023-07-10T07:08:04 | 0.168 | 0.558 | 422.33002
-NZyWNp-UaDdjJB071Er | 2023-07-10T07:38:04 | 0.18 | 0.558 | 422.34198
-NZycFH2xUsjnOV74NIq | 2023-07-10T08:08:04 | 0.191 | 0.558 | 422.354
-NZyj6jmgpR1sX_88EoR | 2023-07-10T08:38:04 | 0.204 | 0.558 | 422.36697
-NZypzC_4t6gIAt56gVQ | 2023-07-10T09:08:04 | 0.216 | 0.558 | 422.37802
-NZywqeBjE9D69S9ddx2 | 2023-07-10T09:38:04 | 0.227 | 0.558 | 422.38901
-NZz2i6vZjyKKxaB-1-N | 2023-07-10T10:08:04 | 0.238 | 0.558 | 422.401
-NZz9_ZZG4QtbLwU7XMT | 2023-07-10T10:38:04 | 0.25 | 0.558 | 422.41202
-NZzGS1F8AQrK2Lbifw9 | 2023-07-10T11:08:04 | 0.262 | 0.558 | 422.423
-NZzNJU7ytZ2HAqqbpmU | 2023-07-10T11:38:04 | 0.297 | 0.558 | 422.45898
-NZzUAwlRv8NTsD30X01 | 2023-07-10T12:08:04 | 0.322 | 0.558 | 422.48398
-NZza2OiZtIoljr6AxFC | 2023-07-10T12:38:04 | 0.343 | 0.558 | 422.50604
-NZzgur979m5OIpKZ1c8 | 2023-07-10T13:08:04 | 0.355 | 0.558 | 422.51703
-NZznmJRLR0LfBZrXewB | 2023-07-10T13:38:04 | 0.367 | 0.558 | 422.52802
-NZzudn7OylH24cs16g5 | 2023-07-10T14:08:04 | 0.379 | 0.558 | 422.54099
-N_-0WDzYP9LlbplvHFN | 2023-07-10T14:38:04 | 0.391 | 0.558 | 422.552
-N_-7NgKXCwpkBtCRsrM | 2023-07-10T15:08:04 | 0.436 | 0.558 | 422.59698
-N_-EF8JvuI7Rhf5w8L_ | 2023-07-10T15:38:04 | 0.481 | 0.558 | 422.64398
-N_-L6aoEDDvce5D667A | 2023-07-10T16:08:04 | 0.495 | 0.558 | 422.65704
-N_-Rz3fl55E-oCwFwsQ | 2023-07-10T16:38:04 | 0.521 | 0.558 | 422.68201
-N_-YqWYPgxEp0Pds3Eo | 2023-07-10T17:08:04 | 0.538 | 0.558 | 422.70001
-N_-ehyuQ9vwLuM1n--f | 2023-07-10T17:38:04 | 0.554 | 0.558 | 422.71698
-N_-l_Z5mfzq4ugVzBuo | 2023-07-10T18:08:04 | 0.57 | 0.558 | 422.733
-N_-sRuwiXT_Znm3FhQ5 | 2023-07-10T18:38:04 | 0.587 | 0.558 | 422.74899
-N_-zJLo_2tVYleOqe4M | 2023-07-10T19:08:04 | 0.602 | 0.558 | 422.76398
-N_05AoYyHh2vXznKyvT | 2023-07-10T19:38:04 | 0.616 | 0.558 | 422.77896
-N_0IujP4xqrHHEvIWxW | 2023-07-10T20:38:04 | 0.647 | 0.558 | 422.80902
-N_0PmAqcOcYsUSyXHfd | 2023-07-10T21:08:04 | 0.662 | 0.558 | 422.82401
-N_0WddLRW3hB6lZ3Scm | 2023-07-10T21:38:04 | 0.677 | 0.558 | 422.84003
-N_0cW5N3t0iuTNdkRt4 | 2023-07-10T22:08:04 | 0.693 | 0.558 | 422.85602
-N_0jNYmp6qxNQUkx8wT | 2023-07-10T22:38:04 | 0.709 | 0.558 | 422.871
-N_0qF-uTW_a5FHrsfav | 2023-07-10T23:08:04 | 0.723 | 0.558 | 422.88596
-N_0x6T4_Q6kMUMkWFEO | 2023-07-10T23:38:04 | 0.739 | 0.558 | 422.90201
-N_12ywI-DYDX5LtDh1R | 2023-07-11T00:08:04 | 0.005 | 0.752 | 422.91901

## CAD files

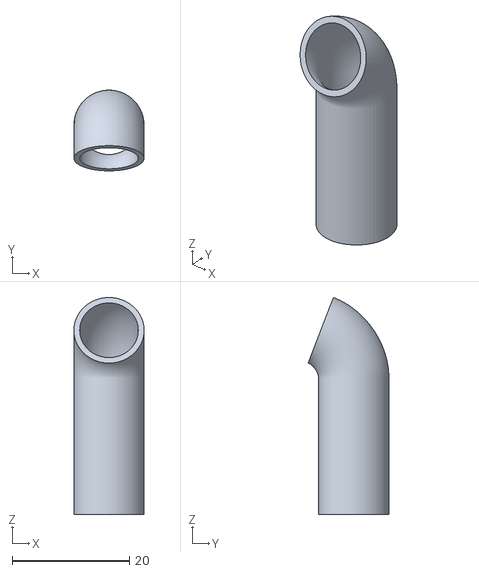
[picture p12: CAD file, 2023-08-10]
models/final/3d print/pipe.stl
12.0 x 13.8 x 37.0

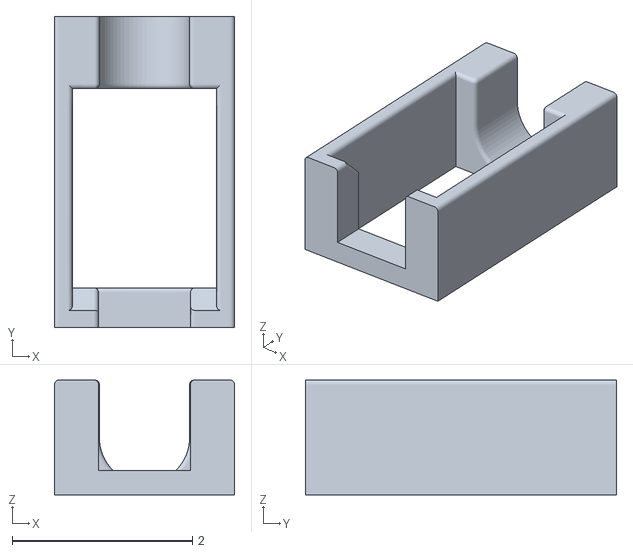
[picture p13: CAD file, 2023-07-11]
models/work in progress/3dprint/dcJackHolder.stl
2.00 x 3.45 x 1.27

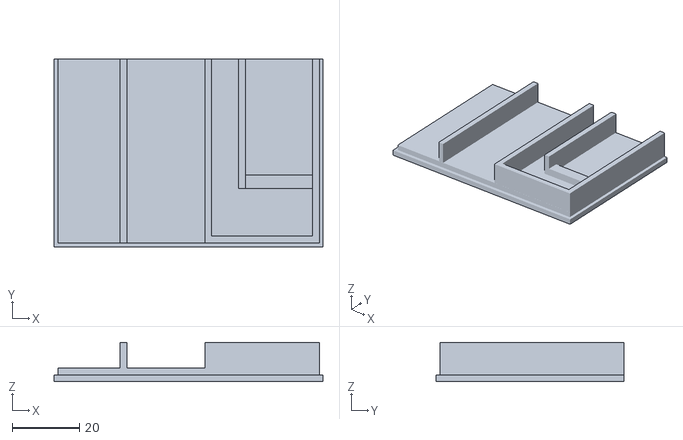
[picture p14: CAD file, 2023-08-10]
models/work in progress/3dprint/rev7/device_base.stl
80.0 x 56.0 x 11.7

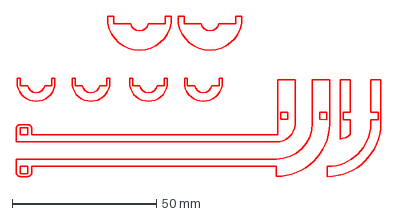
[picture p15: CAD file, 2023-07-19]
models/work in progress/drawings/rev5-1/2_5mmParts.dxf
126.7 x 55.6 mm

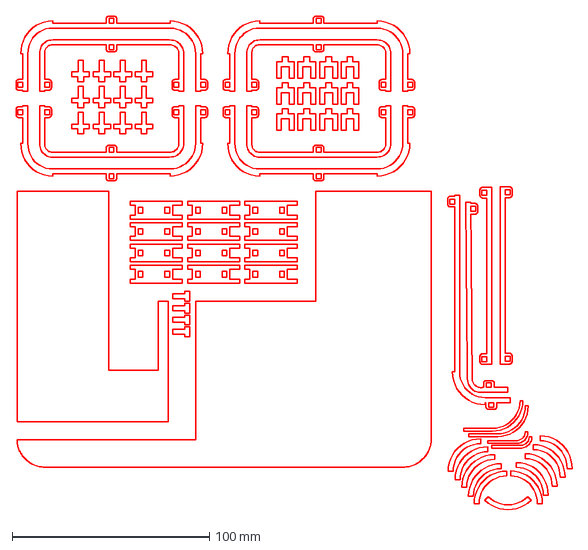
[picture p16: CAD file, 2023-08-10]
models/work in progress/drawings/rev7_NewType/2_5mm_wood.dxf
281.9 x 250.2 mm

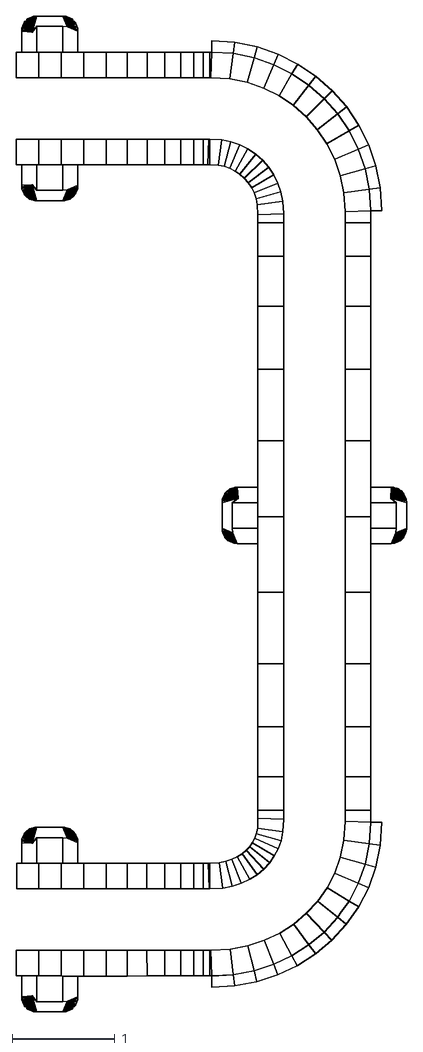
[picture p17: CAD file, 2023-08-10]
models/work in progress/drawings/rev7_NewType/tracks/t2.svg.dxf
3.81 x 9.71

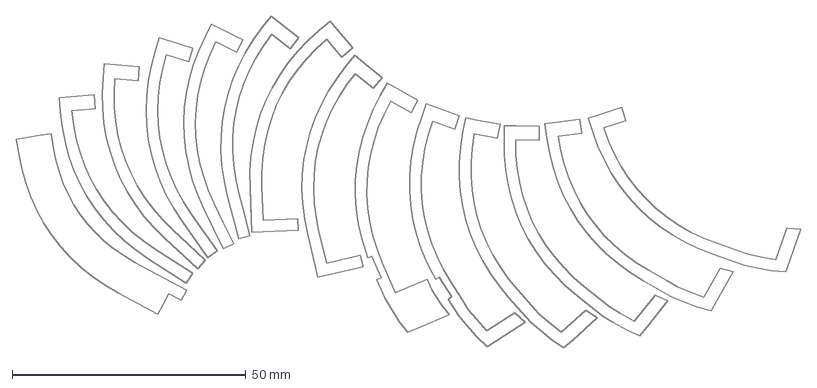
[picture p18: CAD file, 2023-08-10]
models/work in progress/drawings/rev9/marble platform.dxf
167.6 x 70.9 mm

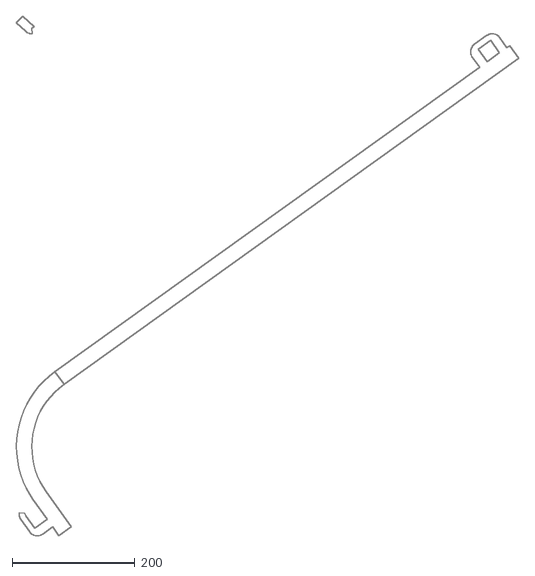
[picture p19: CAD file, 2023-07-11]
models/work in progress/drawings/tracks/track5_page1.dxf
817.2 x 845.7

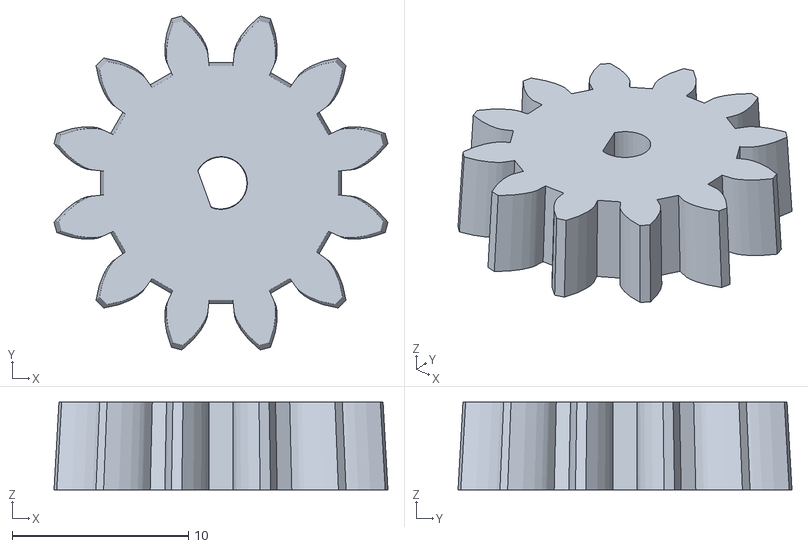
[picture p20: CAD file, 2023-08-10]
models/final/3d print/smallGear.stl
19.0 x 19.0 x 4.99

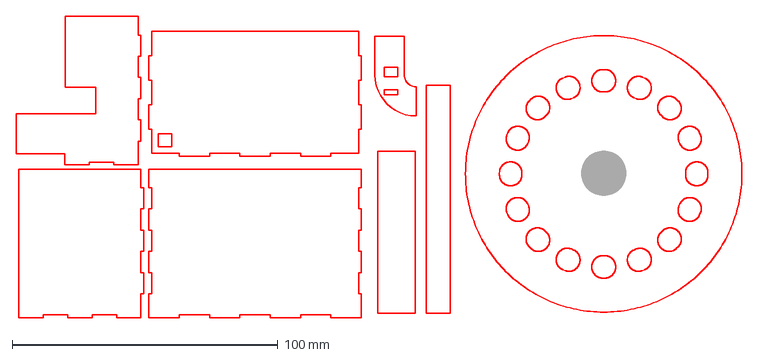
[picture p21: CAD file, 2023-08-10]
models/final/laser cut/1mm_wood.dxf
273.0 x 113.3 mm

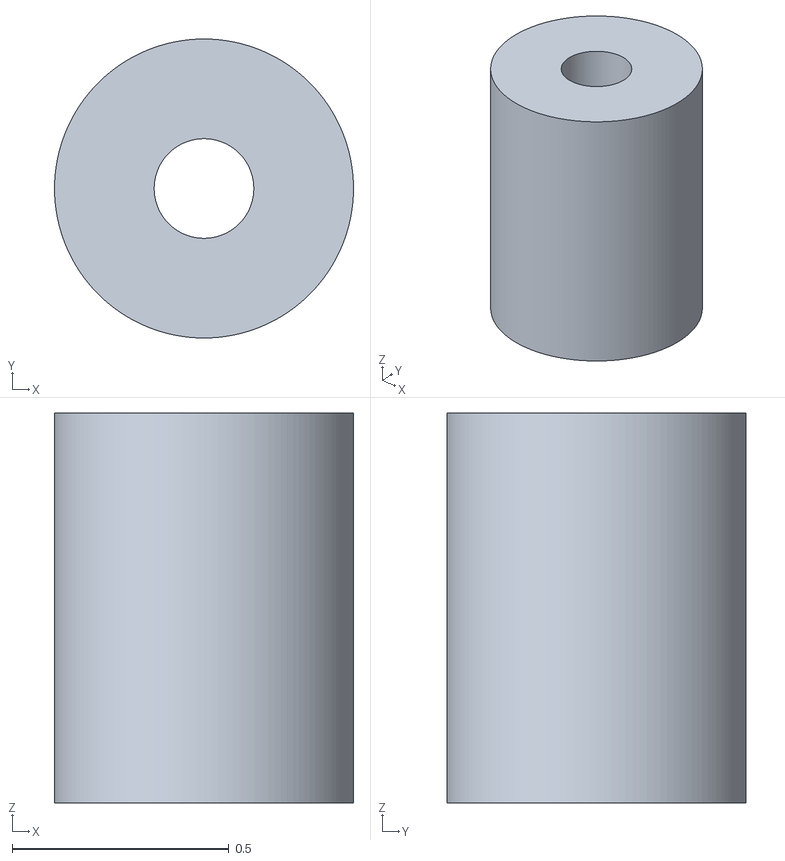
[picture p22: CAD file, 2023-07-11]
models/work in progress/3dprint/fixer.stl
0.69 x 0.69 x 0.9

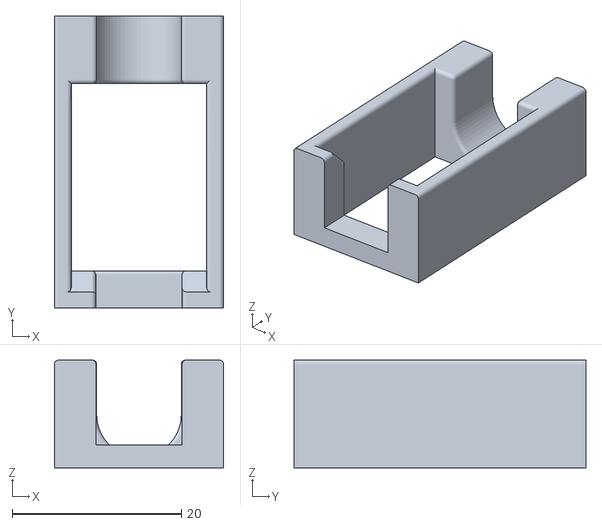
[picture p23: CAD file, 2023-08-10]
models/work in progress/3dprint/rev6_newtype/powerHolder.stl
20.0 x 34.5 x 12.8

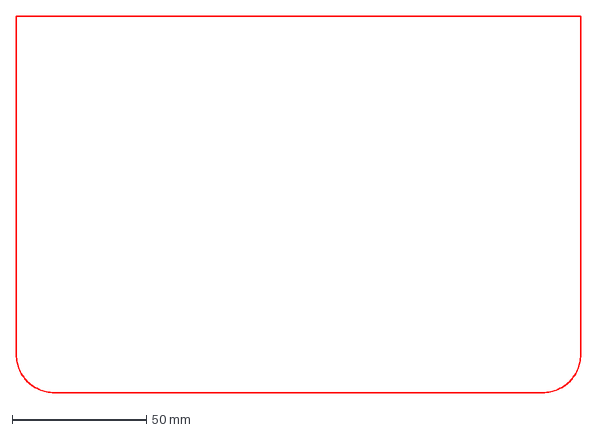
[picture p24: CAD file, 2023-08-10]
models/work in progress/drawings/final/1_8mm_acrylic.dxf
210.0 x 140.0 mm

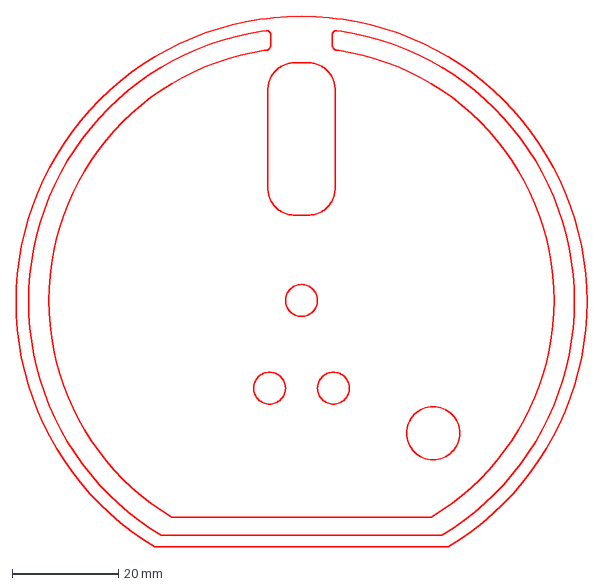
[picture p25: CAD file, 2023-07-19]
models/work in progress/drawings/rev5-1/backboard.dxf
107.4 x 99.7 mm

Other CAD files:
models/final/laser cut/5mm_acrylic_top cover.dwg
models/work in progress/drawings/final/top cover.dwg
models/work in progress/drawings/rev7_NewType/ref_Base.dxf
models/final/3d print/gearBase.stl
models/final/3d print/gearTower.stl
models/final/3d print/largeGear.stl
models/final/3d print/motorBox_base.stl
models/final/3d print/motorBox_top.stl
models/final/laser cut/10mm_acrylic.dxf
models/final/laser cut/1mm_wood_control box.dxf
models/final/laser cut/5mm_acrylic.dxf
models/work in progress/3dprint/3dparts.obj
models/work in progress/3dprint/3dparts.stl
models/work in progress/3dprint/gearGear.stl
models/work in progress/3dprint/gearPinion.stl
models/work in progress/3dprint/motorHolder.stl
models/work in progress/3dprint/parts.stl
models/work in progress/3dprint/rev3/gear_small.stl
models/work in progress/3dprint/rev3/motorHolder_Base.stl
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

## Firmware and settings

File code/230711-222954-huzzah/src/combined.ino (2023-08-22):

#include <cmath>
#include "secrets.h"
#include <Arduino.h>
#if defined(ESP32)
#include <WiFi.h>
#include <Firebase_ESP_Client.h>
#elif defined(ESP8266)
#include <ESP8266WiFi.h>
#include <FirebaseESP8266.h>
#elif defined(ARDUINO_RASPBERRY_PI_PICO_W)
#include <WiFi.h>
#include <FirebaseESP8266.h>
#endif

// Provide the token generation process info.
#include <addons/TokenHelper.h>

// Provide the RTDB payload printing info and other helper functions.
#include <addons/RTDBHelper.h>

#include <DNSServer.h>
#include <WebServer.h>
#include <WiFiManager.h>

// JSON Library
#include <ArduinoJson.h>

// LED Library
#include <Adafruit_NeoPixel.h>
#ifdef __AVR__
#include <avr/power.h> // Required for 16 MHz Adafruit Trinket
#endif

// MQTT Library
#include <PubSubClient.h>

// Adafruit Motor Shield Library
#include <Adafruit_MotorShield.h>

#include <map>

// Time Library
#include "time.h"

// MQTT Server address
// TODO: Change this address dynamically in App or Web
#define MQTT_SERVER "mqtt.cetools.org"
#define MQTT_TOPIC "UCL/OPS/107/EM/gosund/#"

#define LED_PIN 13

// How many NeoPixels are attached to the Arduino?
#define NUMPIXELS 40  // Popular NeoPixel ring size
#define CENTRE_LED 19 // Centre LED index

#define PROJECT_ID "energycelab"

#define TOUCH_PIN 27

#define BUTTON1_PIN 15
#define BUTTON2_PIN 14

// Define Firebase objects
FirebaseData fbdo;
FirebaseAuth auth;
FirebaseConfig config;

// Define JSON size
DynamicJsonDocument incomingLive(256);
DynamicJsonDocument MQTTincoming(512);
DynamicJsonDocument firestoreJSON(1024);
DynamicJsonDocument preferenceJSON(256);

// Define NeoPixel object
Adafruit_NeoPixel pixels(NUMPIXELS, LED_PIN, NEO_GRB + NEO_KHZ800);

// Define WiFi client
WiFiClient espClient;
// Define MQTT client
PubSubClient mqttClient(espClient);

// Create the motor shield object with the default I2C address
Adafruit_MotorShield AFMS = Adafruit_MotorShield();
// Select which 'port' M1, M2, M3 or M4. In this case, M1
Adafruit_DCMotor *myMotor = AFMS.getMotor(1);

// Define a data structure for MQTT data processing
struct DeviceData
{
  unsigned long lastUpdated;
  int power;
  float today;
  float yesterday;
  float total;
  String time;
  String startDate;
};

//
// Define global variables
//
unsigned long liveDataMillis = 0;
unsigned long historyDataMillis = 0;
unsigned long testMillis = 0;
unsigned long liveTransitionMillis = 0;
unsigned long dailyLEDMillis = 0;
unsigned long lastTransitionMillis = 0;
unsigned long lastSaveAnimationLEDMillis = 0;
unsigned long lastSaveMillis = 0;
unsigned long Button1StateChangeTime = 0;
unsigned long Button2StateChangeTime = 0;
const unsigned long DebounceTime = 10;
int deviceCount = 0;
int transitionWait = 250;
int saveWait = 3000;
int liveLEDCount = 0;
int lastLEDCount = 0;
int historyLEDCount = 0;
int saveAnimationLastLEDCount = NUMPIXELS;
int liveLEDDefault = 19;
int maximumLivePower = 300;
int maxLiveLED = 19;
int motorSpeed = 0;
int savedMarble = 0;
int targetMarble = 0;
int maxMarble = 10;
int isTouched = 0;
int startTime = 8;
int endTime = 19;
std::map<String, DeviceData> deviceList;
FirebaseJson liveOverallJson;
FirebaseJson historyOverallJson;
String defaultPath = "device/";
String userUID;
bool initialising = true;
bool liveLEDInitialising = true;
bool saveAnimationInit = true;
bool isDebug = false;
bool debugInit = true;
bool Button1Pressed = false;
bool Button2Pressed = false;
bool saveMarbleRequired = false;
bool isSavingFinished = false;
bool isLEDOn = true;
bool stopWheel = false;
bool stopSaving = false;
bool isRestarting = false;
unsigned int livePower = 0;
unsigned int liveFactor = 15;
float todayFactor = 20;
// TODO: Read this from user preference
double unitEnergyCost = 33.2;
int targetCost = 50;

// Time Library Parameters
const char *ntpServer = "pool.ntp.org";
const long gmtOffset_sec = 0;
const int daylightOffset_sec = 0;

bool getUserPreference(String path = defaultPath.c_str())
{
  // Print path using printf
  Serial.printf("path: %s\n", path.c_str());
  FirebaseJson preferenceJSON;
  bool isRead = Firebase.Firestore.getDocument(&fbdo, PROJECT_ID, "", path);
  isRead ? Serial.println("Read Success") : Serial.println("Read Fail");
  FirebaseJson json;
  FirebaseJsonData result;
  json.setJsonData(fbdo.payload());
  if (!json.get(result, "fields/preference"))
  {
    Serial.println("User preference not found. Creating new preference.");
    preferenceJSON.set("fields/preference/mapValue/fields/unitCost/doubleValue", unitEnergyCost);
    preferenceJSON.set("fields/preference/mapValue/fields/targetCost/integerValue", targetCost);
    preferenceJSON.set("fields/preference/mapValue/fields/isLEDOn/booleanValue", isLEDOn);
    preferenceJSON.set("fields/preference/mapValue/fields/isForceStop/booleanValue", isDebug);
    preferenceJSON.set("fields/preference/mapValue/fields/stopWheel/booleanValue", stopWheel);
    preferenceJSON.set("fields/preference/mapValue/fields/stopSaving/booleanValue", stopSaving);
    preferenceJSON.set("fields/preference/mapValue/fields/isRestarting/booleanValue", isRestarting);
    preferenceJSON.set("fields/preference/mapValue/fields/startTime/integerValue", startTime);
    preferenceJSON.set("fields/preference/mapValue/fields/endTime/integerValue", endTime);

    Firebase.Firestore.patchDocument(&fbdo, PROJECT_ID, "", path, preferenceJSON.raw(), "preference");
    return true;
  }
  else
  {
    Serial.println("User preference found.");
    json.setJsonData(fbdo.payload());
    if (json.get(result, "fields/preference/mapValue/fields/unitCost/doubleValue"))
    {
      unitEnergyCost = result.to<double>();
    }
    if (json.get(result, "fields/preference/mapValue/fields/targetCost/integerValue"))
    {
      targetCost = result.to<int>();
    }
    if (json.get(result, "fields/preference/mapValue/fields/isLEDOn/booleanValue"))
    {
      isLEDOn = result.to<bool>();
    }
    if (json.get(result, "fields/preference/mapValue/fields/isForceStop/booleanValue"))
    {
      isDebug = result.to<bool>();
    }
    if (json.get(result, "fields/preference/mapValue/fields/stopWheel/booleanValue"))
    {
      stopWheel = result.to<bool>();
    }
    if (json.get(result, "fields/preference/mapValue/fields/stopSaving/booleanValue"))
    {
      stopSaving = result.to<bool>();
    }
    if (json.get(result, "fields/preference/mapValue/fields/isRestarting/booleanValue"))
    {
      isRestarting = result.to<bool>();
    }
    if (json.get(result, "fields/preference/mapValue/fields/startTime/integerValue"))
    {
      startTime = result.to<int>();
    }
    if (json.get(result, "fields/preference/mapValue/fields/endTime/integerValue"))
    {
      endTime = result.to<int>();
    }
    return true;
  }

  return false;
}

void setup()
{
  Serial.begin(115200);
  Serial.println();
  Serial.println();

  pixels.begin(); // INITIALIZE NeoPixel strip object (REQUIRED)
  pixels.clear(); // Set all pixel colors to 'off'
  pixels.setBrightness(50);
  rainbowFade2White(5, 3, 3);
  pixels.clear(); // Set all pixel colors to 'off'

  pinMode(BUTTON1_PIN, INPUT_PULLUP);
  pinMode(BUTTON2_PIN, INPUT_PULLUP);

  WiFiManager wifiManager;
  // Uncomment to reset saved settings
  // wifiManager.resetSettings();

  wifiManager.setAPCallback([](WiFiManager *myWiFiManager)
                            { Serial.println("Connect to the AP named \"ESPap\" and open any web page to setup."); });

  // Fetches ssid and password, and tries to connect,
  // if it does not connect, it starts an access point with the specified name
  // and goes into a blocking loop awaiting configuration.
  if (!wifiManager.autoConnect("MarbleMachine", "thereisnospoon"))
  {
    Serial.println("Failed to connect, we should reset as see if it connects");
    delay(3000);
    // Reset device
    ESP.restart();
    delay(5000);
  }

  // If you get here you have connected to the WiFi
  Serial.println("Connected.");

  Serial.println();
  Serial.print("Connected with IP: ");
  Serial.println(WiFi.localIP());
  Serial.println();

  Serial.printf("Firebase Client v%s\n\n", FIREBASE_CLIENT_VERSION);

  /* Assign the api key (required) */
  config.api_key = API_KEY;

  /* Assign the user sign in credentials */
  // auth.user.email = USER_EMAIL;
  // auth.user.password = USER_PASSWORD;
  auth.user.email = TEST_EMAIL;
  auth.user.password = TEST_PASSWORD;

  /* Assign the callback function for the long running token generation task */
  config.token_status_callback = tokenStatusCallback; // see addons/TokenHelper.h

  // Limit the size of response payload to be collected in FirebaseData
  fbdo.setResponseSize(2048);

  Firebase.begin(&config, &auth);
  Serial.println(Firebase.ready() ? "Firebase is Ready." : "Firebase is Not ready.");

  Firebase.reconnectWiFi(true);

  // Save the user UID
  userUID = auth.token.uid.c_str();
  // Update the default path
  defaultPath += userUID;
  defaultPath += "/";

  // Set MQTT Server
  mqttClient.setServer(MQTT_SERVER, 1883);
  mqttClient.setCallback(callback);
  mqttClient.setBufferSize(512);

  if (!AFMS.begin())
  { // create with the default frequency 1.6KHz
    // if (!AFMS.begin(1000)) {  // OR with a different frequency, say 1KHz
    Serial.println("Could not find Motor Shield. Check wiring.");
    while (1)
      ;
  }
  Serial.println("Motor Shield found.");

  // init and get the time
  configTime(gmtOffset_sec, daylightOffset_sec, ntpServer);

  Serial.println(getCurrentTime());

  // Touch sensor
  pinMode(33, INPUT_PULLUP);

  getUserPreference(defaultPath.c_str());
}

void loop()
{
  if (isRestarting == true)
  {
    // Change isRestarting to false in Firestore
    FirebaseJson restartJson;
    restartJson.set("fields/preference/mapValue/fields/unitCost/doubleValue", unitEnergyCost);
    restartJson.set("fields/preference/mapValue/fields/targetCost/integerValue", targetCost);
    restartJson.set("fields/preference/mapValue/fields/isLEDOn/booleanValue", isLEDOn);
    restartJson.set("fields/preference/mapValue/fields/isForceStop/booleanValue", isDebug);
    restartJson.set("fields/preference/mapValue/fields/stopWheel/booleanValue", stopWheel);
    restartJson.set("fields/preference/mapValue/fields/stopSaving/booleanValue", stopSaving);
    restartJson.set("fields/preference/mapValue/fields/isRestarting/booleanValue", false);
    restartJson.set("fields/preference/mapValue/fields/startTime/integerValue", startTime);
    restartJson.set("fields/preference/mapValue/fields/endTime/integerValue", endTime);
    Firebase.Firestore.patchDocument(&fbdo, PROJECT_ID, "", defaultPath.c_str(), restartJson.raw(), "preference");
    ESP.restart();
  }
  // if time is after 7pm and before 8am, turn off the LED using timeinfo
  struct tm tinfo;
  getLocalTime(&tinfo);
  // Serial.printf("Hour: %d\n", tinfo.tm_hour);
  if (tinfo.tm_hour >= endTime && tinfo.tm_hour < startTime)
  // if (tinfo.tm_min >= 7 && tinfo.tm_min < 8)
  {
    isDebug = true;
  }
  else
  {
    isDebug = false;
  }

  checkButton1();
  checkButton2();
  if (isDebug)
  {
    myMotor->setSpeed(0);
    myMotor->run(RELEASE);
    pixels.clear();
  }
  else
  {
    ////////////////////////////////
    // Connect MQTT Client
    ////////////////////////////////
    if (!mqttClient.connected())
    {
      Serial.println("MQTT Client not connected");
      reconnect();
    }

    ////////////////////////////////
    // Check for inactive devices every minute
    // Update overall data
    // Update User preference
    ////////////////////////////////
    if (millis() - liveDataMillis > 60000 && !saveMarbleRequired)
    {
      for (auto it = deviceList.begin(); it != deviceList.end();)
      {
        if (millis() - it->second.lastUpdated > 60000)
        {                            // 60000 milliseconds = 1 minute
          it = deviceList.erase(it); // remove the device from the list
          deviceCount--;             // decrement the device count
        }
        else
        {
          ++it;
        }
      }
      // Update Live Overall data
      Serial.println(updateOverallLive());

      // Check marble saving
      if (stopSaving == false)
      {
        saveMarbleRequired = checkMarbleSaving();
      }

      // Refresh User Preference
      getUserPreference(defaultPath.c_str());

      liveDataMillis = millis();
    }

    ////////////////////////////////
    // Update history data every 30 mins
    ////////////////////////////////
    if (millis() - historyDataMillis > 1800000 && !saveMarbleRequired)
    {
      historyDataMillis = millis();
      Serial.println(updateHistory());
    }

    ///////////////////////////////
    // Get live Data for transition animation
    ///////////////////////////////
    if (Firebase.ready() && !saveMarbleRequired)
    {
      if (millis() - liveTransitionMillis > 60000 || initialising)
      {
        liveTransitionMillis = millis();

        String queryPath = defaultPath;
        queryPath += "sensors/overall/";
        FirebaseJson query;

        query.set("select/fields/[0]/fieldPath", "power");
        query.set("select/fields/[1]/fieldPath", "time");
        query.set("from/collectionId", "live");
        query.set("from/allDescendants", false);
        query.set("orderBy/field/fieldPath", "time");
        query.set("orderBy/direction", "DESCENDING");
        query.set("limit", 1);

        JsonArray queryResult = queryFirestore(queryPath, query);

        if (queryResult.size() > 0)
        {
          livePower = queryResult[0]["document"]["fields"]["power"]["integerValue"].as<int>();
          Serial.printf("Power: %d\n", livePower);
        }
        else
        {
          Serial.println("No query result");
        }

        // Set LED attribute
        liveLEDCount = int(mapValue(livePower, 0, roundToHundred(maximumLivePower), 0, maxLiveLED));
        if (stopWheel == false)
        {
          motorSpeed = int(mapValue(livePower, 0, roundToHundred(maximumLivePower), 20, 50));
        }
        else
        {
          motorSpeed = 0;
        }
      }
    }

    ////////////////////////////////
    // Set NeoPixel color based on live data
    ////////////////////////////////
    if (!saveMarbleRequired && isLEDOn)
    {
      // Show LED animation
      if (millis() - lastTransitionMillis > transitionWait)
      {
        pixels.setPixelColor(CENTRE_LED, pixels.Color(255, 0, 0));
        if (liveLEDInitialising)
        {
          pixels.setPixelColor(CENTRE_LED + lastLEDCount, pixels.Color(232, 229, 88));
          pixels.show();
          lastLEDCount++;
          if (lastLEDCount == liveLEDCount)
          {
            liveLEDInitialising = false;
          }
        }
        else
        {
          if (liveLEDCount - lastLEDCount > 0)
          {
            for (int i = 1; i < liveLEDCount; i++)
            {
              pixels.setPixelColor(CENTRE_LED + i, pixels.Color(232, 229, 88));
            }
            pixels.show();
            lastLEDCount++;
          }
          else if (liveLEDCount - lastLEDCount < 0)
          {
            pixels.setPixelColor(CENTRE_LED + lastLEDCount, pixels.Color(0, 0, 0));
            pixels.show();
            lastLEDCount--;
          }
          else
          {
            pixels.setPixelColor(CENTRE_LED + lastLEDCount, pixels.Color(232, 229, 88));
            pixels.show();
          }
        }
      }

      // Get history data and set LED
      if (millis() - dailyLEDMillis > 600000 || initialising)
      {
        dailyLEDMillis = millis();

        String queryPath = defaultPath;
        queryPath += "sensors/overall/";
        FirebaseJson query;

        query.set("select/fields/[0]/fieldPath", "today");
        query.set("select/fields/[1]/fieldPath", "time");
        query.set("from/collectionId", "history");
        query.set("from/allDescendants", false);
        query.set("orderBy/field/fieldPath", "time");
        query.set("orderBy/direction", "DESCENDING");
        query.set("limit", 1);

        JsonArray queryResult = queryFirestore(queryPath, query);

        if (queryResult.size() > 0)
        {
          float today = queryResult[0]["document"]["fields"]["today"]["doubleValue"].as<float>();
          Serial.printf("Today: %f\n", today);
          historyLEDCount = int(mapValue(today, 0, 2, 0, CENTRE_LED - 1));
          // historyLEDCount = int(map(today, 0, 2, 0, CENTRE_LED - 1));
        }
        else
        {
          Serial.println("No query result");
        }

        // Set LED attribute
        for (int i = 0; i < CENTRE_LED; i++)
        {
          pixels.setPixelColor(i, pixels.Color(0, 0, 0));
        }
        for (int i = CENTRE_LED - 1; i > CENTRE_LED - historyLEDCount; i--)
        {
          pixels.setPixelColor(i, pixels.Color(232, 229, 88));
          pixels.show();
        }
      }
    }

    ////////////////////////////////
    // Set Motor Speed
    ////////////////////////////////
    if (!saveMarbleRequired)
    {
      myMotor->run(FORWARD);
      myMotor->setSpeed(motorSpeed);
    }

    ////////////////////////////////
    // Marble Saving Sequence
    ////////////////////////////////
    if (saveMarbleRequired == true)
    {
      if (isSavingFinished == true)
      {
        // wait for the last marble to drop
        if (millis() - lastSaveMillis > saveWait * 1.3)
        {
          Serial.println("Stopping saving sequence");
          myMotor->run(RELEASE);
          myMotor->run(FORWARD);
          myMotor->setSpeed(motorSpeed);
          saveMarbleRequired = false;
          saveAnimationInit = true;
          isSavingFinished = false;
          // LED Reset
          lastLEDCount = 0;
          pixels.clear();
          Serial.printf("liveLEDCount: %d\n", liveLEDCount);
          Serial.printf("historyLEDCount: %d\n", historyLEDCount);
          for (int i = CENTRE_LED - 1; i > CENTRE_LED - historyLEDCount; i--)
          {
            pixels.setPixelColor(i, pixels.Color(232, 229, 88));
            pixels.show();
          }
        }
      }
      else
      {
        if (saveAnimationInit == true)
        {
          myMotor->run(RELEASE);
          pixels.clear(); // Set all pixel colors to 'off'
          saveAnimationInit = false;
        }

        // Set LED animation
        if (millis() - lastSaveAnimationLEDMillis > transitionWait / 5 && isLEDOn == true)
        {
          pixels.clear();
          pixels.setPixelColor(saveAnimationLastLEDCount - 2, pixels.Color(232, 239, 247));
          pixels.setPixelColor(saveAnimationLastLEDCount - 1, pixels.Color(133, 186, 247));
          pixels.setPixelColor(saveAnimationLastLEDCount, pixels.Color(10, 120, 247));
          pixels.show();
          saveAnimationLastLEDCount--;
          if (saveAnimationLastLEDCount == 0)
          {
            saveAnimationLastLEDCount = NUMPIXELS;
          }
          lastSaveAnimationLEDMillis = millis();
        }

        myMotor->run(BACKWARD);
        myMotor->setSpeed(30);
        isTouched = digitalRead(33) == LOW ? true : false;
        if ((millis() - lastSaveMillis > saveWait) && (isTouched == true))
        {
          Serial.println("Touch sensor is pressed");
          savedMarble++;
          lastSaveMillis = millis();
          Serial.printf("savedMarble: %d / targetMarble: %d\n", savedMarble, targetMarble);
        }
        if (savedMarble >= targetMarble)
        {
          Serial.println("Saving is finished");
          isSavingFinished = true;
        }
      }
    }
    else
    {
      myMotor->run(FORWARD);
    }

    initialising = false;

    if (isLEDOn == false)
    {
      pixels.clear();
      pixels.show();
    }

    lastTransitionMillis = millis();

    // Regularly check for MQTT connection
    mqttClient.loop();
  }
}
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

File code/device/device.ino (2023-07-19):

#include "secrets.h"
#include <Arduino.h>
#if defined(ESP32)
#include <WiFi.h>
#include <FirebaseESP32.h>
#elif defined(ESP8266)
#include <ESP8266WiFi.h>
#include <FirebaseESP8266.h>
#endif
#include <PubSubClient.h>
// Provide the token generation process info.
#include <addons/TokenHelper.h>
// Provide the RTDB payload printing info and other helper functions.
#include <addons/RTDBHelper.h>
#include <ArduinoJson.h>
#include <map>

#define MQTT_SERVER "mqtt.cetools.org"
#define MQTT_TOPIC "UCL/OPS/107/EM/gosund/#"
// Firebase database address
#define DATABASE_URL "https://energycelab-default-rtdb.europe-west1.firebasedatabase.app"

// Define the Firebase Data object
FirebaseData fbdo;
// Define the FirebaseAuth data for authentication data
FirebaseAuth auth;
// Define the FirebaseConfig data for config data
FirebaseConfig config;
// Define Json handling
DynamicJsonDocument incoming(512);
// Define WiFi client
WiFiClient espClient;
// Define MQTT client
PubSubClient client(espClient);

// Define a struct to hold the data for each device
struct DeviceData {
  unsigned long lastUpdated;
  int power;
  float today;
  float yesterday;
  float total;
  String time;
  String startDate;
};

unsigned long liveDataMillis = 0;
unsigned long historyDataMillis = 0;
unsigned long testMillis = 0;
int deviceCount = 0;
// int led = LED_BUILTIN;
std::map<String, DeviceData> deviceList;
FirebaseJson liveOverallJson;
FirebaseJson historyOverallJson;
String defaultPath = "/TEST/";
String liveOverallPath = defaultPath;

void setup()
{
    Serial.begin(115200);

    WiFi.begin(WIFI_SSID, WIFI_PASSWORD);
    Serial.println("Connecting to Wi-Fi");
    // Try to connect WiFi, LED(13) blinking shows the progress
    while (WiFi.status() != WL_CONNECTED)
    {
      delay(1000);
      Serial.println("Connecting to WiFi...");
    }
    Serial.println();
    Serial.print("Connected with IP: ");
    Serial.println(WiFi.localIP());
    Serial.println();

    Serial.printf("Firebase Client v%s\n\n", FIREBASE_CLIENT_VERSION);

    /* Assign the api key (required) */
    config.api_key = API_KEY;
    /* Assign the user sign in credentials */
    auth.user.email = USER_EMAIL;
    auth.user.password = USER_PASSWORD;
    /* Assign the RTDB URL */
    config.database_url = DATABASE_URL;

    Firebase.reconnectWiFi(true);
    fbdo.setResponseSize(4096);

    String base_path = "/UsersData/";

    /* Assign the callback function for the long running token generation task */
    config.token_status_callback = tokenStatusCallback; // see addons/TokenHelper.h

    /* Initialize the library with the Firebase authen and config */
    Firebase.begin(&config, &auth);

    // Or refresh token manually
    // Firebase.refreshToken(&config);

    client.setServer(MQTT_SERVER, 1883);
    client.setCallback(callback);
    client.setBufferSize(512);

    // Set paths for Firebase
    liveOverallPath += auth.token.uid.c_str();
    liveOverallPath += "/UCL/OPS/107/EM/Live/overall";
}


void loop() {
  if (!client.connected()) {
    reconnect();
  }
  // Check for inactive devices every minute and Update overall data
  if (millis() - liveDataMillis > 60000) {
    for (auto it = deviceList.begin(); it != deviceList.end(); ) {
      if (millis() - it->second.lastUpdated > 60000) {  // 60000 milliseconds = 1 minute
        it = deviceList.erase(it); // remove the device from the list
        deviceCount--; // decrement the device count
      } else {
        ++it;
      }
    }
    liveDataMillis = millis();

    Serial.println(updateOverallLive());
  }
  // Update history data every 30 mins
  if (millis() - historyDataMillis > 1800000) {
    historyDataMillis = millis();
    Serial.println(updateHistory());
  }
  client.loop();
}


void callback(char* topic, byte* payload, unsigned int length) {
  String topicString(topic);
  int lastSlash = topicString.lastIndexOf('/');
  String lastSection = topicString.substring(0, lastSlash);  // Get the string up to the last '/'
  lastSlash = lastSection.lastIndexOf('/');  // Find the position of the second last '/'
  String deviceName = lastSection.substring(lastSlash + 1);  // Extract the section after the second last '/'

  // Check number of device
  if (topicString.indexOf("LWT") != -1 && deviceList.find(deviceName) == deviceList.end()) {
    // TODO : Count the number of device regularly 
    deviceCount++;
    DeviceData data;
    data.lastUpdated = millis();
    deviceList[deviceName] = data;

    Serial.print("Number of devices: ");
    Serial.println(deviceCount);

    Serial.print("Contents of topicList:");
    for (auto& device : deviceList) {
      Serial.print(device.first);
      Serial.print(", ");
    }
    Serial.println("");
  }

  // Check SENSOR value
  if (topicString.indexOf("SENSOR") != -1) {
    DeviceData data;
    data.lastUpdated = millis(); // Record received time
    char msg[length+1]; //Convert the bytes data to char
    memcpy (msg, payload, length);
    msg[length] = '\0';
    DeserializationError error = deserializeJson(incoming, msg); // Convert the Char data to Json format
    if (error) {
      Serial.print(F("deserializeJson() failed: "));
      Serial.println(error.f_str());
      return;
    }
    data.time = String(incoming["Time"].as<const char*>());
    data.startDate = String(incoming["ENERGY"]["TotalStartTime"].as<const char*>());
    data.total = incoming["ENERGY"]["Total"];
    data.today = incoming["ENERGY"]["Today"];
    data.yesterday = incoming["ENERGY"]["Yesterday"];
    data.power = incoming["ENERGY"]["Power"];

    deviceList[deviceName] = data;

    String livePath = defaultPath;
    livePath += auth.token.uid.c_str();
    livePath += "/UCL/OPS/107/EM/Live/";
    livePath += deviceName;

    FirebaseJson liveJson;
    liveJson.set("time", data.time);
    liveJson.set("power", data.power);

    liveOverallJson.set("time", data.time);
    historyOverallJson.set("time", data.time);

    if (Firebase.pushJSON(fbdo, livePath, liveJson)){
      Serial.printf("Push data... %s\n", "ok");
    }else{
      Serial.printf("Error: \n%s", fbdo.errorReason().c_str());
      refreshFirebase();
    }

    // Serial.printf("Push data... %s\n", Firebase.pushJSON(fbdo, livePath, liveJson) ? "ok" : fbdo.errorReason().c_str());
  }
}

void reconnect() {
  while (!client.connected()) {
    Serial.print("Attempting MQTT connection...");
    if (client.connect("DY_Receiver")) {
      Serial.println("connected");
      Serial.print("Subscription is...");
      Serial.println(client.subscribe(MQTT_TOPIC) ? "Success" : "Fail");
      Serial.print("Subscribed Topic is: ");
      Serial.println(MQTT_TOPIC);
    } else {
      Serial.print("failed, rc=");
      Serial.print(client.state());
      Serial.println(" try again in 5 seconds");
      delay(5000);
    }
  }
}

int sumPower() {
  int totalPower = 0;
  for(auto const& pair : deviceList){
    totalPower += pair.second.power;
  }
  return totalPower;
}
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

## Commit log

2023-06-22 work in progress
    [1mmWood.dwg, 1mmWood.dxf, 1mm_fixer.dwg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]
2023-06-22 added board initialising
    [geometryNodes.blend]
2023-06-22 added checking number of devices
2023-07-11 added data receiving and publishing on the device
    [1mmParts.dxf, 2-5mmParts_Rev2.dxf, 2_5mmParts-1.dxf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]
2023-07-12 set LED strip colours every 1 min and hour
2023-07-12 added LED live energy use animation
2023-07-12 added DC motor control
    change speed based on the live value.
2023-07-19 login page wo signup
    [2_5mmParts.dxf, backboard.dxf]
2023-07-25 DB patching
    [cover.dxf]
2023-08-10 working prototype
    [10mm_acrylic.dxf, 1_8mm_acrylic.dxf, 1mm_wood.dxf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]
2023-08-21 added more remote controls by app
    [schematic.fzz]
2023-08-25 updated image materials
    [schematic.fzz]
2023-08-25 organised files
    [10mm_acrylic.dxf, 1_8mm_acrylic.dxf, 1mmParts.dxf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]
